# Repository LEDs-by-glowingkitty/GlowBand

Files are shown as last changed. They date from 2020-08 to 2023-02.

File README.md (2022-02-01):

GlowBand is an exciting LED wristband. For dancing at parties and festivals, for long-time exposure photography, and for everyday situations that need some light.

This project started as "The Glowing Arms Project" (check out the "GlowBand v0.1" folder) and after experimenting with making the project smaller and based on existing PCBs ("GlowBand v0.2" folder) I decided to instead make a custom PCB design ("GlowBand v1.0"). The PCB design is still in development, but I plan to finish the design in the coming months. Stay tuned!

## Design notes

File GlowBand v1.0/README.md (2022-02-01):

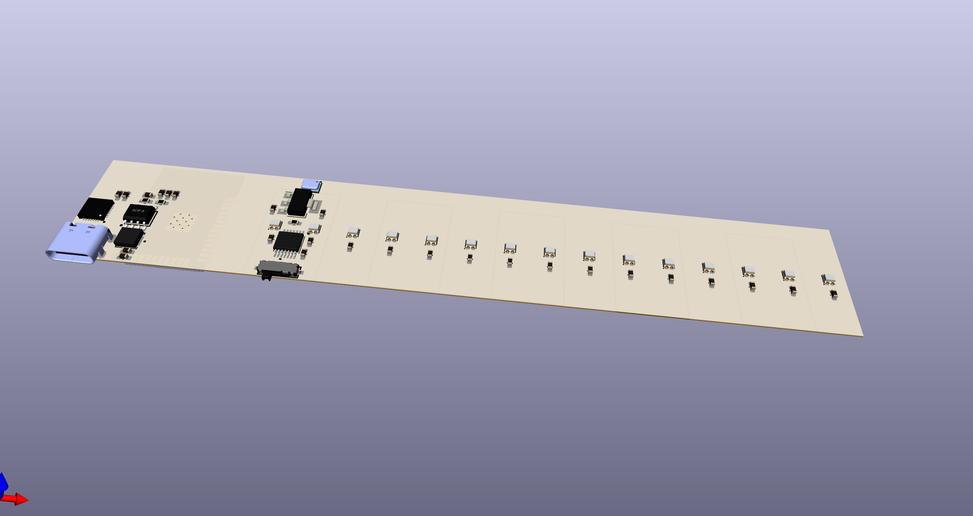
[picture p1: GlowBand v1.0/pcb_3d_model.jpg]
GlowBand


The first version of GlowBand based on a custom PCB design. In development.

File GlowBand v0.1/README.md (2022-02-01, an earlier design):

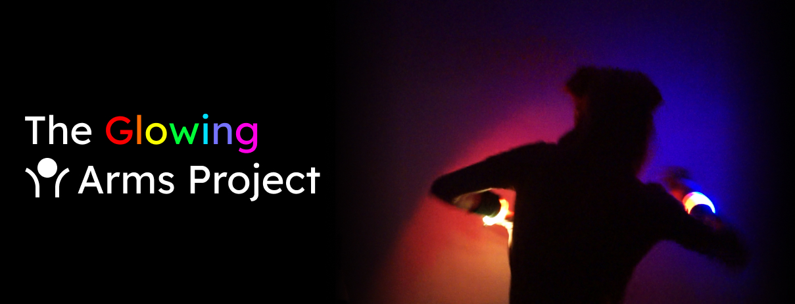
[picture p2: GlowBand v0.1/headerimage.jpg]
The Glowing Arms Project


Build your own LED wristbands for dancing. Controllable via iOS &amp; Android apps. No coding is required.

Want to support the development and stay updated?

<a href="https://www.patreon.com/bePatron?u=24983231">Become a Patreon</a> <a href="https://liberapay.com/glowingkitty/donate">Donate using Liberapay</a>

## Features

- controllable via Bluetooth using the Govee Home [iOS](https://apps.apple.com/us/app/govee-home/id1395696823) and [Android](https://play.google.com/store/apps/details?id=com.govee.home&hl=en) apps
- "Music Mode", reacting to music using the integrated microphone
- "Custom Color Mode", let the LEDs glow in whatever color you like
- and more modes, using the app

## How to build it
Watch this video to learn how you can build the LED wristbands yourself:

[How to build LED wristbands for dancing - no coding required!](https://www.youtube.com/watch?v=rtVQ7AlgY54)
IMAGE ALT TEXT HERE (https://www.youtube.com/watch?v=rtVQ7AlgY54)

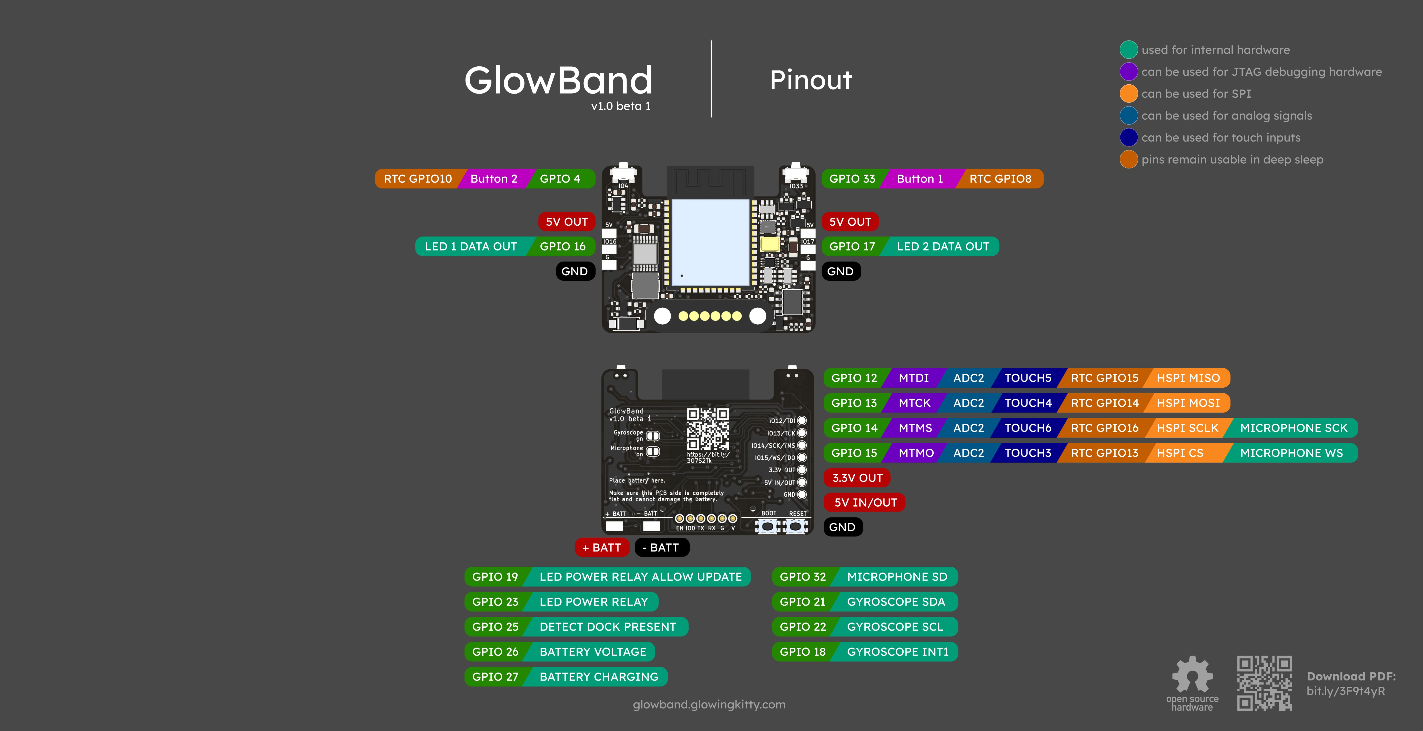
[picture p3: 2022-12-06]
documents/pinout GlowBand v1.0 beta 1.jpg

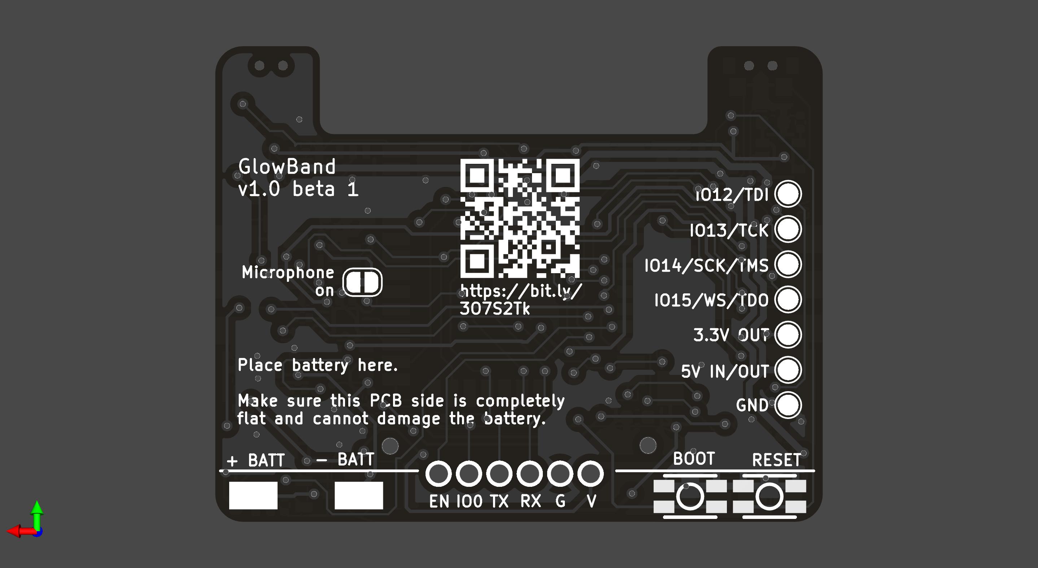
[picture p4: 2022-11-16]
GlowBand PCB/pcb_back.jpg

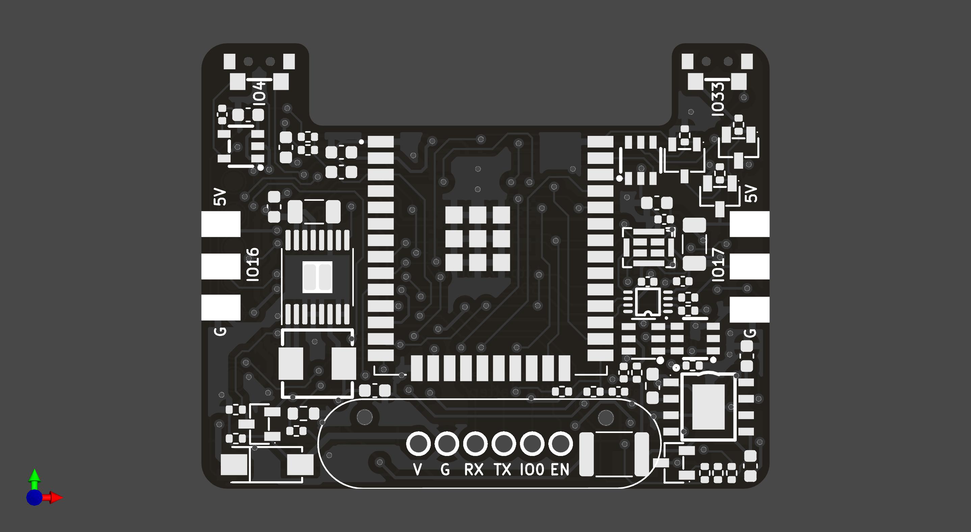
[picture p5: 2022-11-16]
GlowBand PCB/pcb_front.jpg

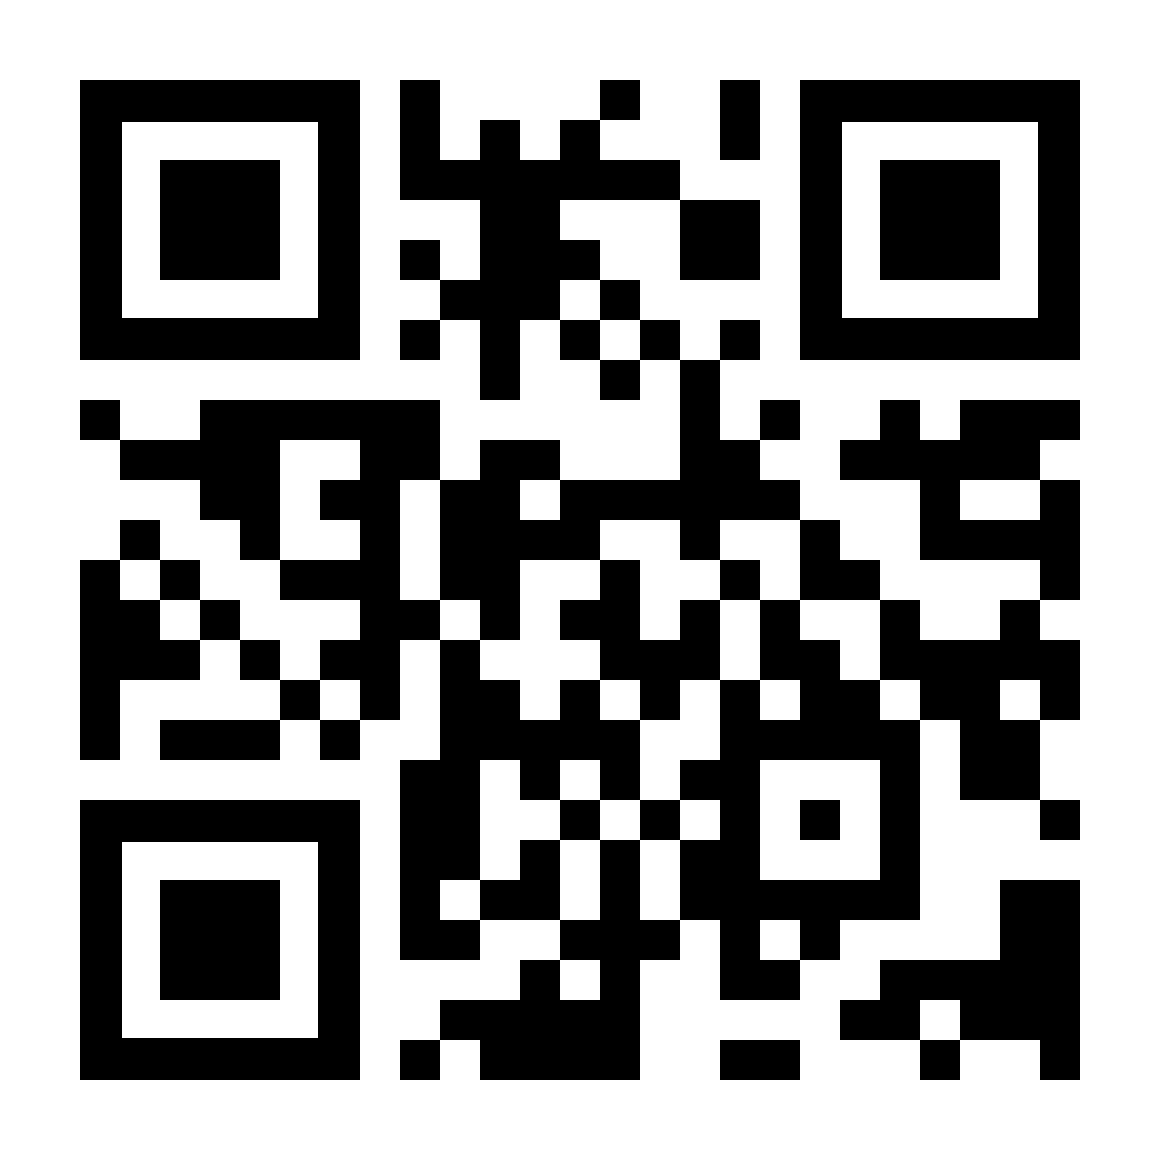
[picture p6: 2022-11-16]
GlowBand PCB/pcb_files.png

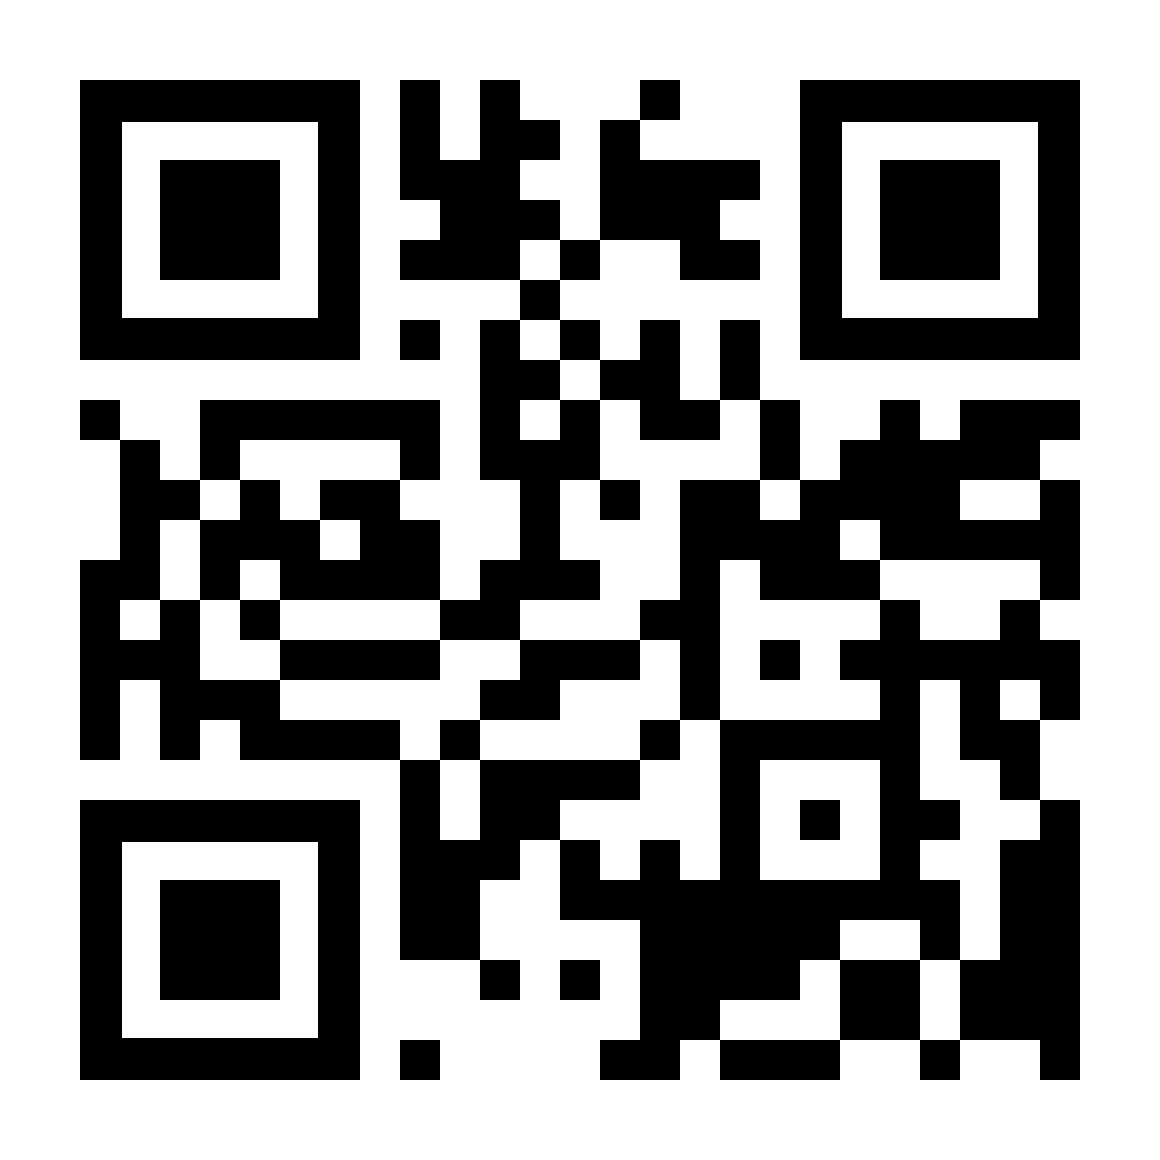
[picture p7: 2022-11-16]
GlowBand Dock PCB/pcb_files.png

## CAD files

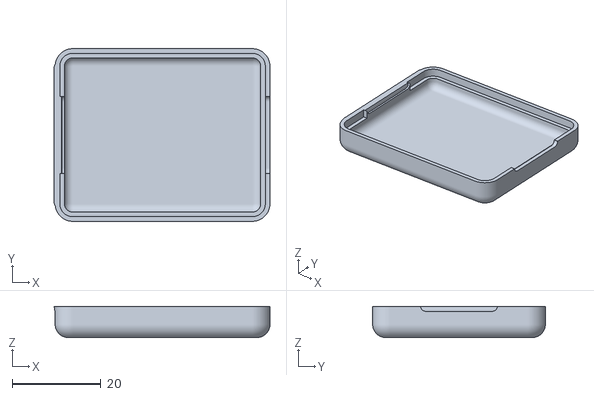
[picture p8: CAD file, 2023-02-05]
3D files/case top.obj
48.8 x 39.0 x 7.05

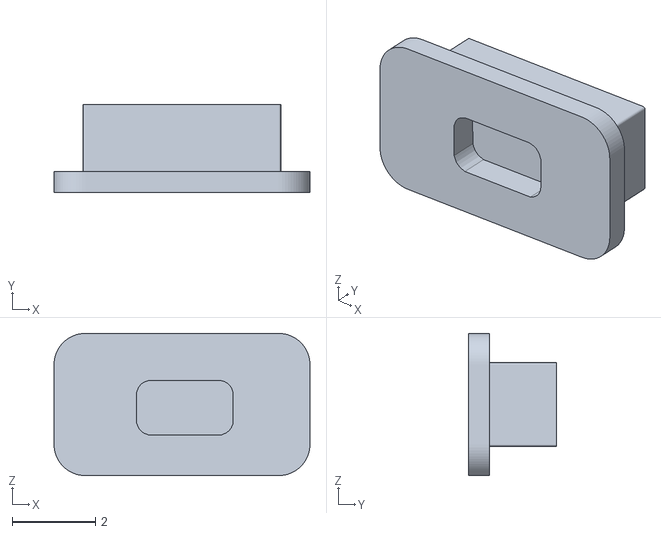
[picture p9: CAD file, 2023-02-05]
3D files/button.obj
6.14 x 2.10 x 3.41

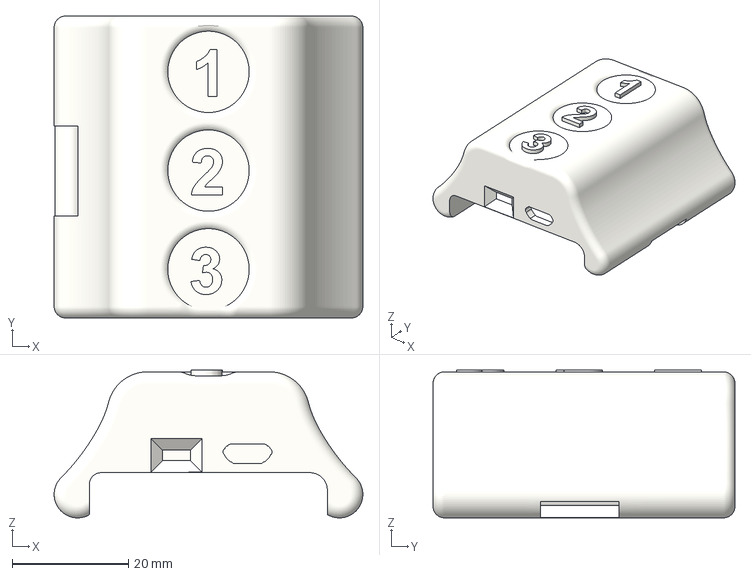
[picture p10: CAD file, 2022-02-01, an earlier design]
archive/GlowBand v0.2/3d printed parts/main case.3mf
53.2 x 52.0 x 25.5 mm

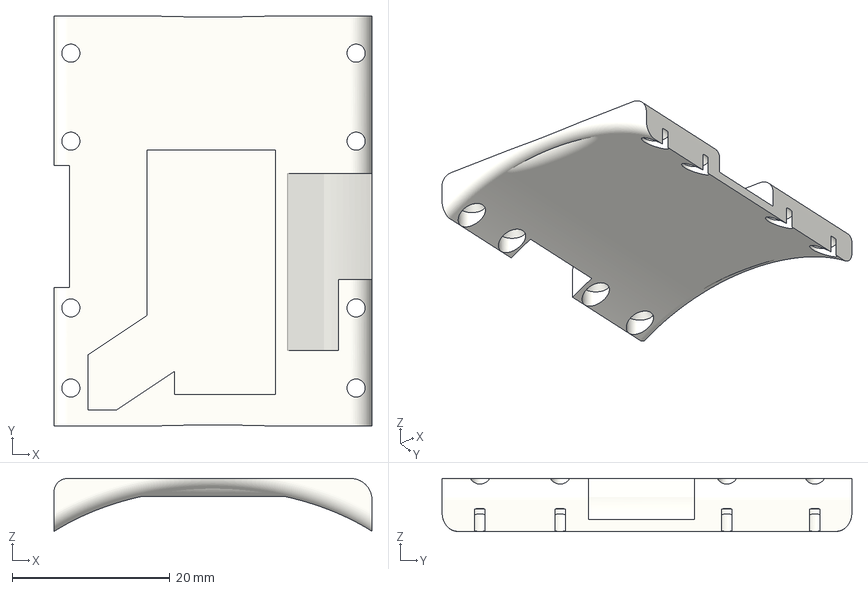
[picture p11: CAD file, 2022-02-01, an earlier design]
archive/GlowBand v0.2/3d printed parts/case cover.3mf
40.4 x 52.0 x 6.73 mm

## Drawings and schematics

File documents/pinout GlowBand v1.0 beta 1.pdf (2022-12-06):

GlowBand | Pinout

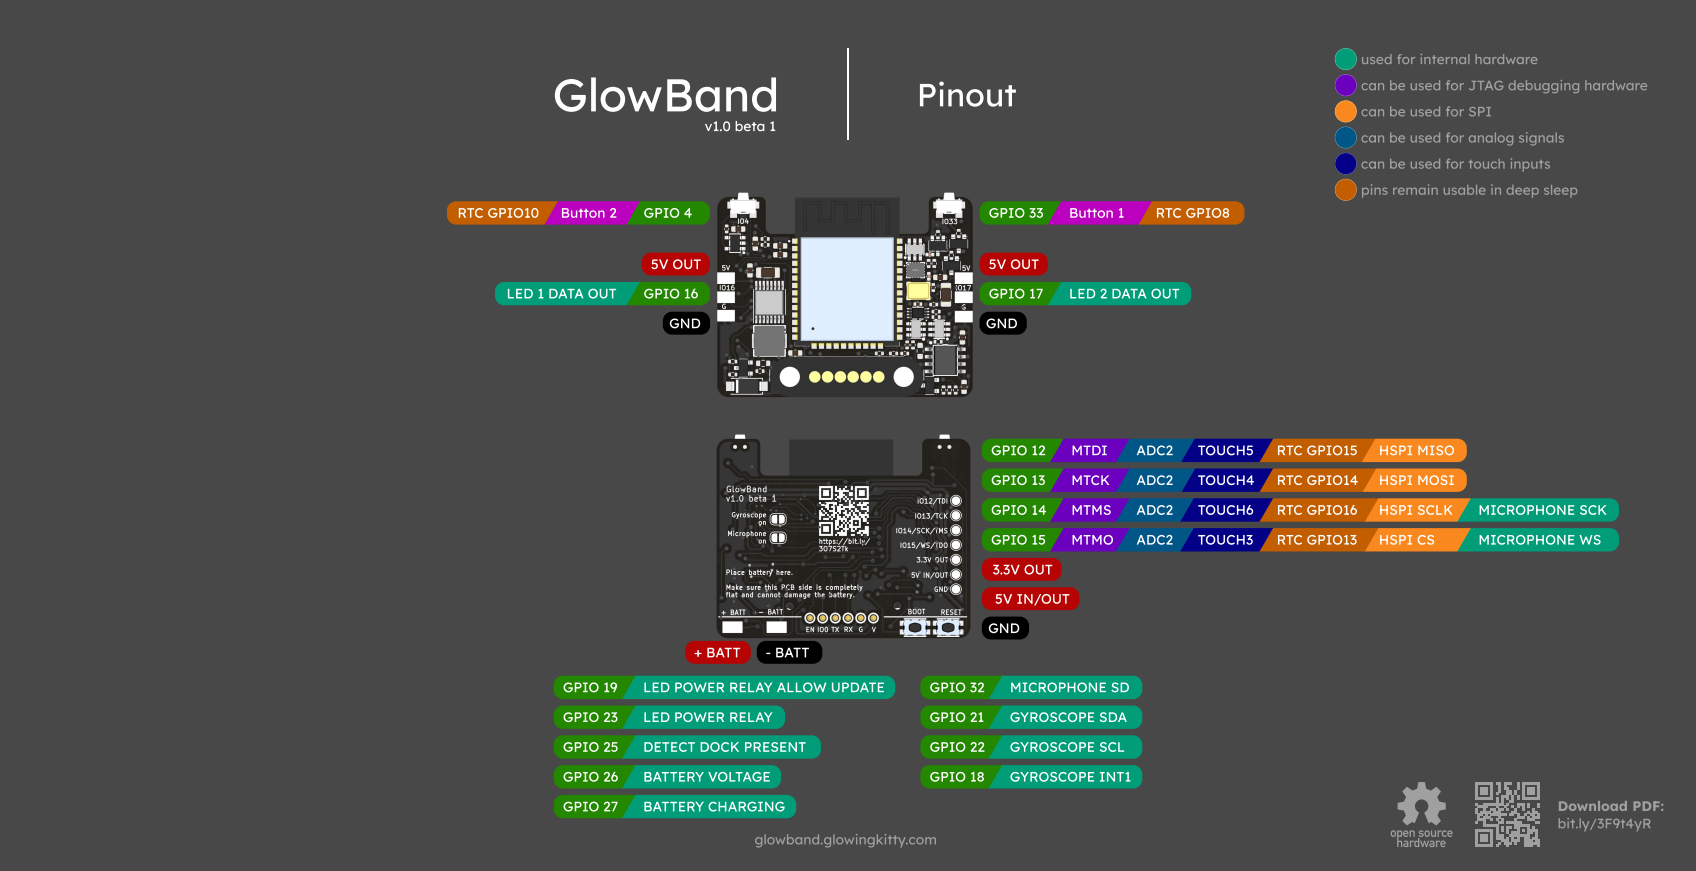
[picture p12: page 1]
GPIO 25; DETECT DOCK PRESENT; GPIO 26; BATTERY VOLTAGE; GPIO 27; BATTERY CHARGING; GPIO 21; GYROSCOPE SDA; GPIO 22; GYROSCOPE SCL; GPIO 18; GYROSCOPE INT1; GPIO 19; LED POWER RELAY ALLOW UPDATE; GPIO 32; MICROPHONE SD; GPIO 23; LED POWER RELAY; v1.0 beta 1; GPIO 33; Button 1; RTC GPIO8; 3.3V OUT; + BATT; 5V IN/OUT; GND; - BATT; GPIO 17; LED 2 DATA OUT; 5V OUT; RTC GPIO10; Button 2; GPIO 4; GPIO 15; MTMO; ADC2; TOUCH3; RTC GPIO13; HSPI CS; MICROPHONE WS; GPIO 14; MTMS; TOUCH6; RTC GPIO16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

used for internal hardware

can be used for JTAG debugging hardware

can be used for SPI

can be used for analog signals

can be used for touch inputs

pins remain usable in deep sleep

5V OUT

LED 1 DATA OUT

GPIO 16

glowband.glowingkitty.com

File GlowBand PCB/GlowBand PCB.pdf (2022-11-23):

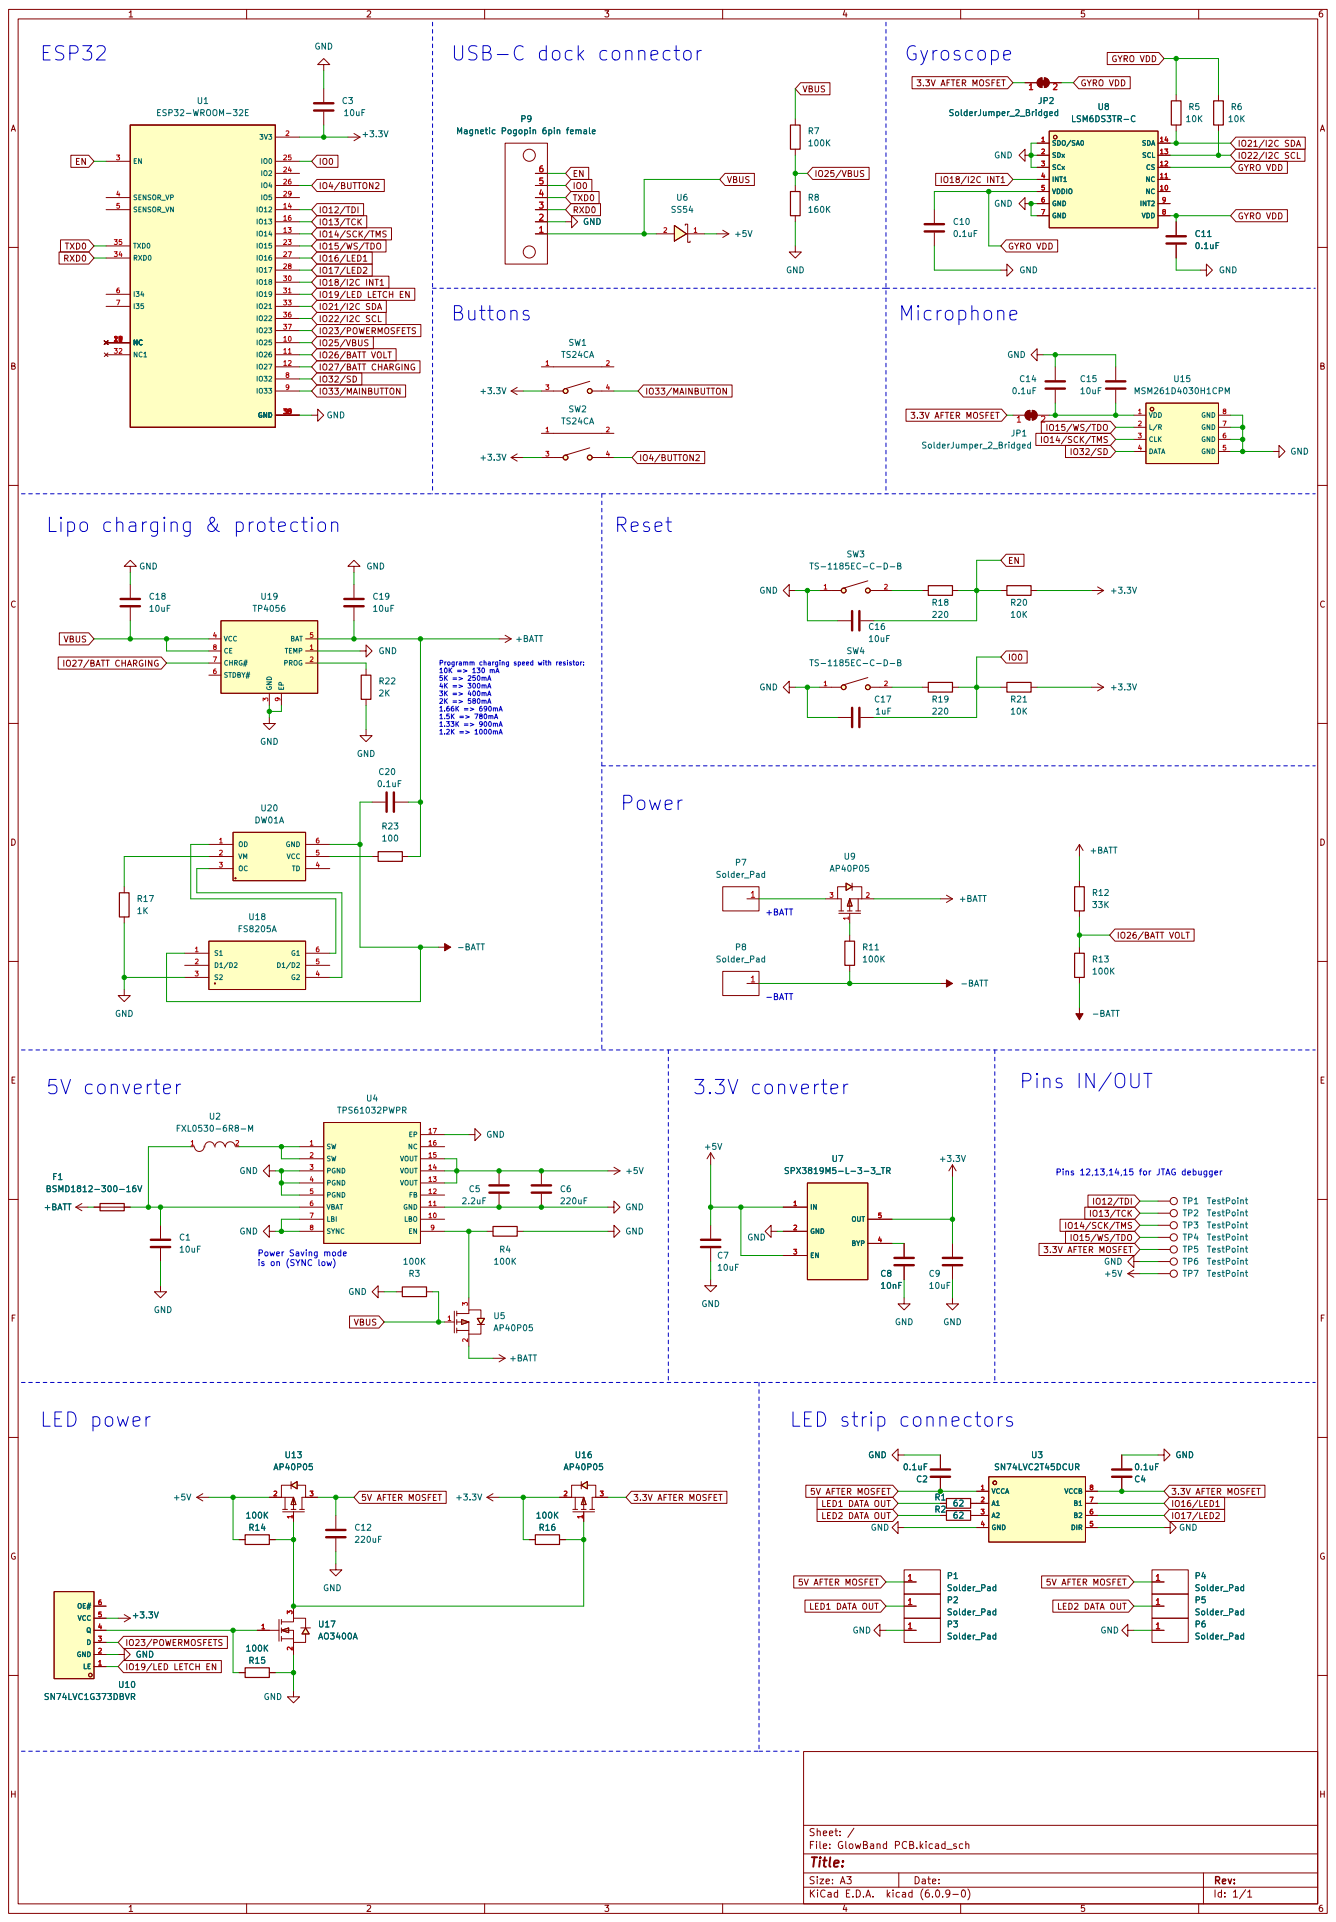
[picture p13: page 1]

3 VCC 4 BAT 5 STDBY# 6 CHRG# 7 CE 8 EP

Programm charging speed with resistor: 10K => 130 mA 5K => 250mA

Pins 12,13,14,15 for JTAG debugger

TP7 TestPoint TP3 TestPoint TP1 TestPoint TP2 TestPoint

Power Saving mode
is on (SYNC low)

File: GlowBand PCB.kicad_sch Sheet: /

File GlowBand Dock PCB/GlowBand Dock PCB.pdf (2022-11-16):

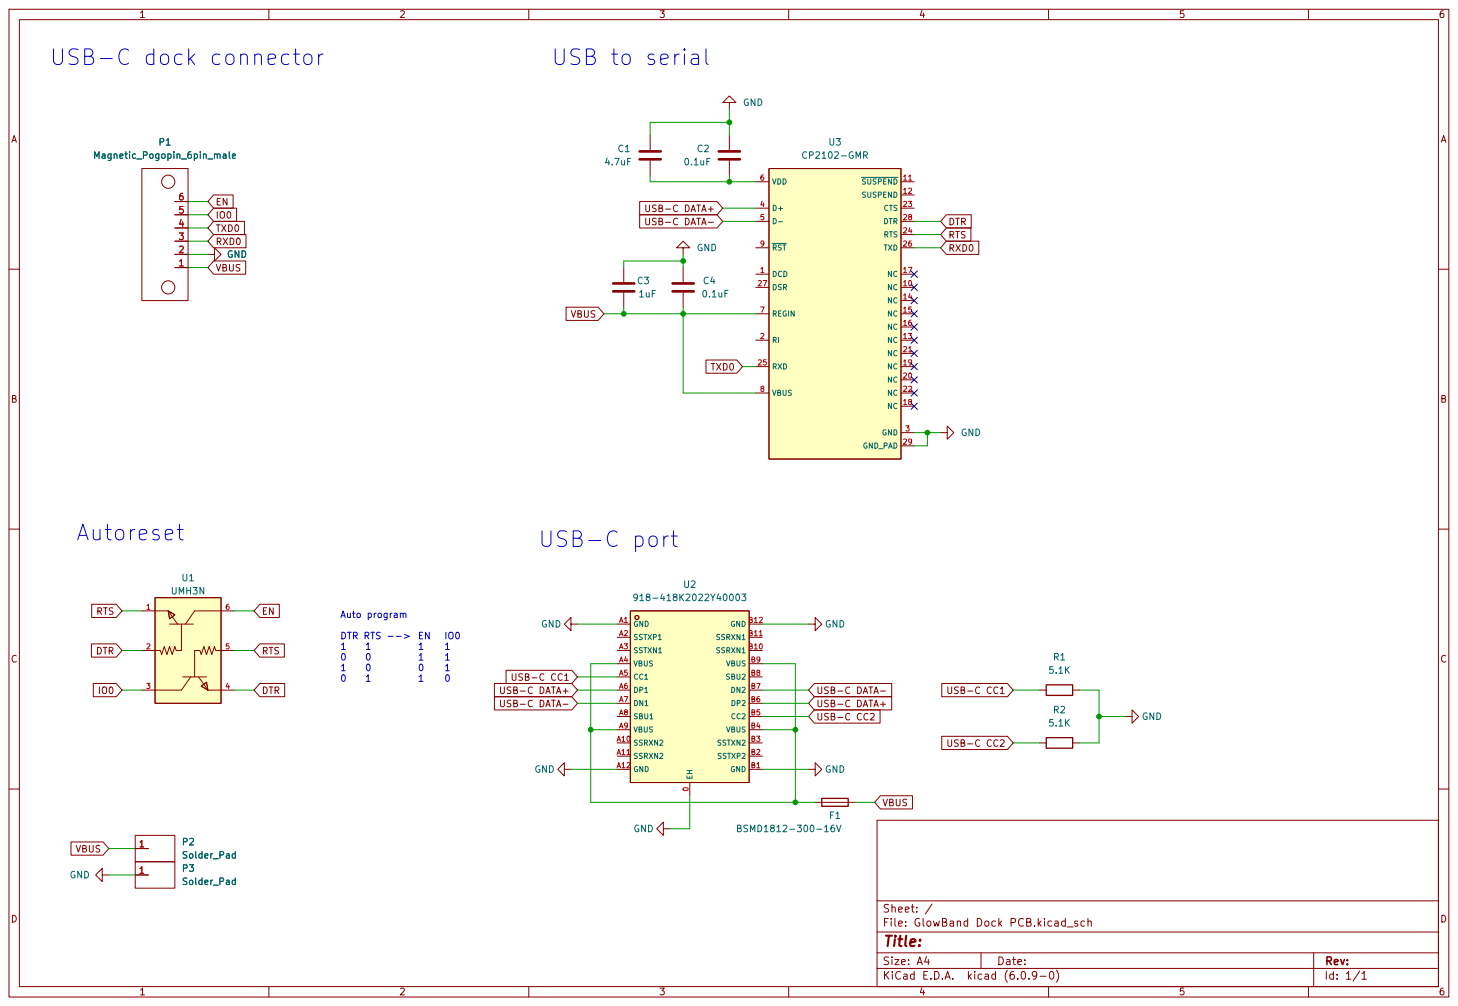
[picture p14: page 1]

0 GND A1 SSRXN2 A10 SSRXN2 A11 GND A12 SSTXP1 A2 SSTXN1 A3 VBUS A4 CC1 A5 DP1 A6 DN1 A7 SBU1 A8 VBUS A9 GND B1 SSRXN1 B10 SSRXN1 B11 GND B12 SSTXP2 B2 SSTXN2 B3 VBUS B4 CC2 B5 DP2 B6 DN2 B7 SBU2 B8 VBUS B9 U2
918-418K2022Y40003 GND

File: GlowBand Dock PCB.kicad_sch Sheet: /
Id: 1/1 Title:

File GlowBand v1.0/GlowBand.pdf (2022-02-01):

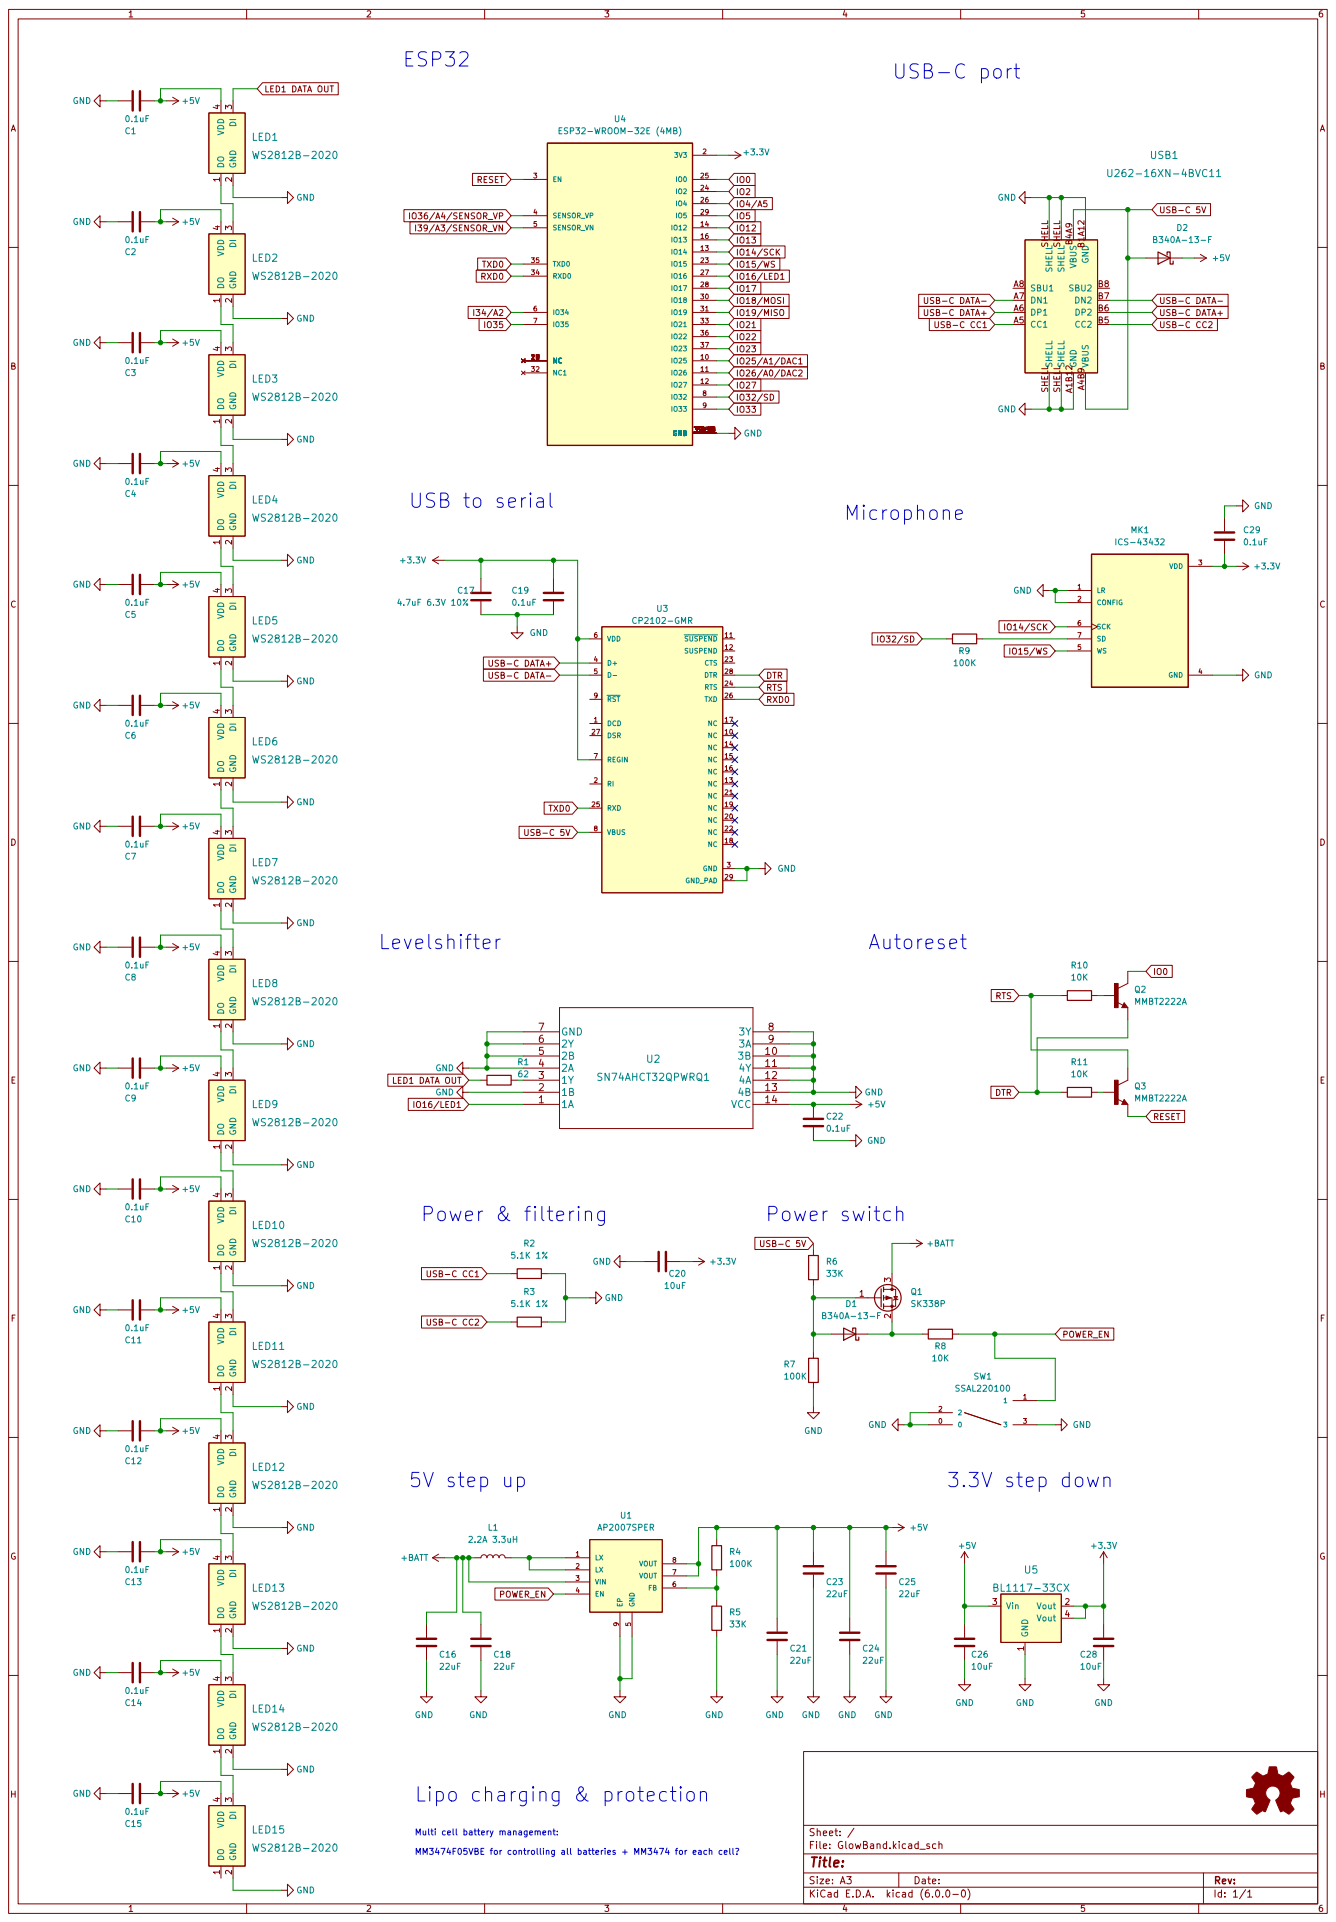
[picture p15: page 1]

Microphone USB to serial

RTS USB-C 5V Power switch

5 FB 6 VOUT 7 VOUT 8 EP

Multi cell battery management:

MM3474F05VBE for controlling all batteries + MM3474 for each cell?

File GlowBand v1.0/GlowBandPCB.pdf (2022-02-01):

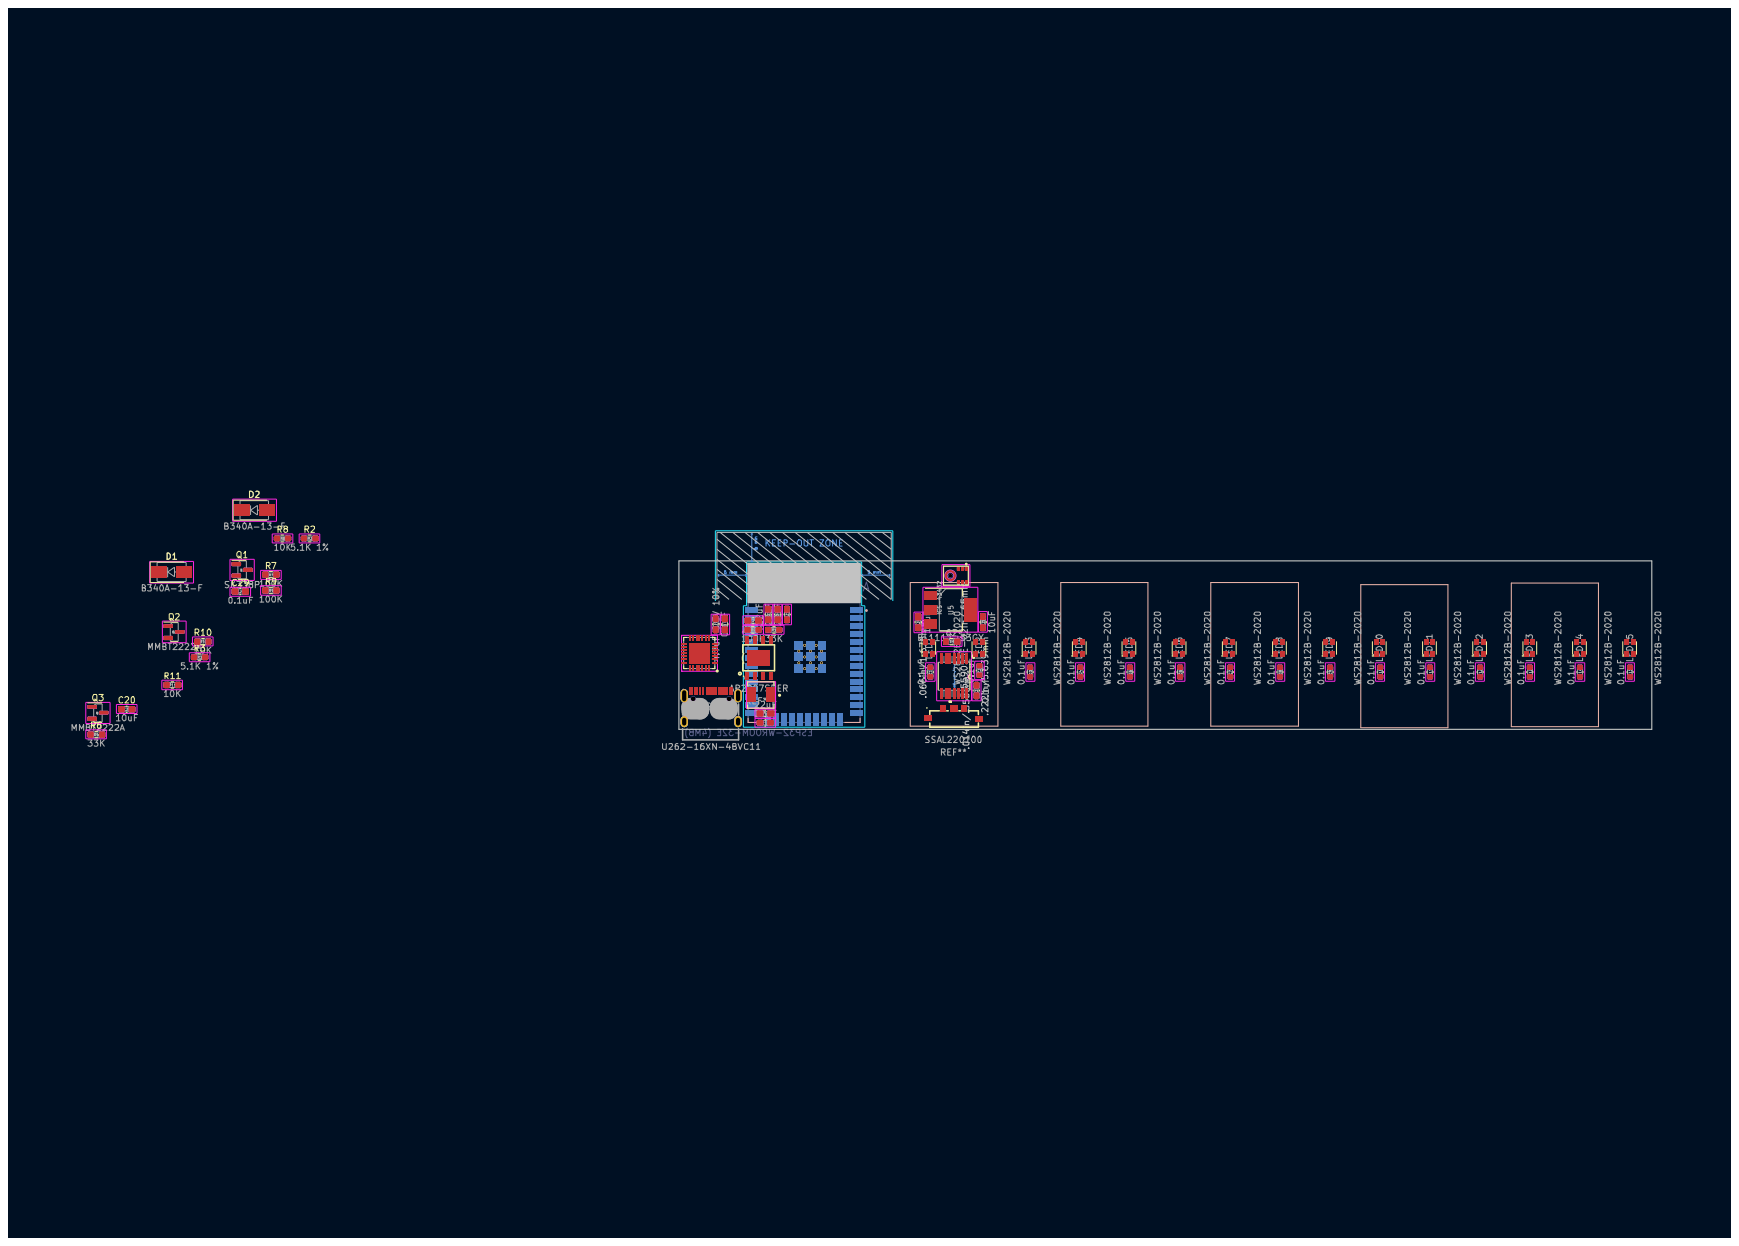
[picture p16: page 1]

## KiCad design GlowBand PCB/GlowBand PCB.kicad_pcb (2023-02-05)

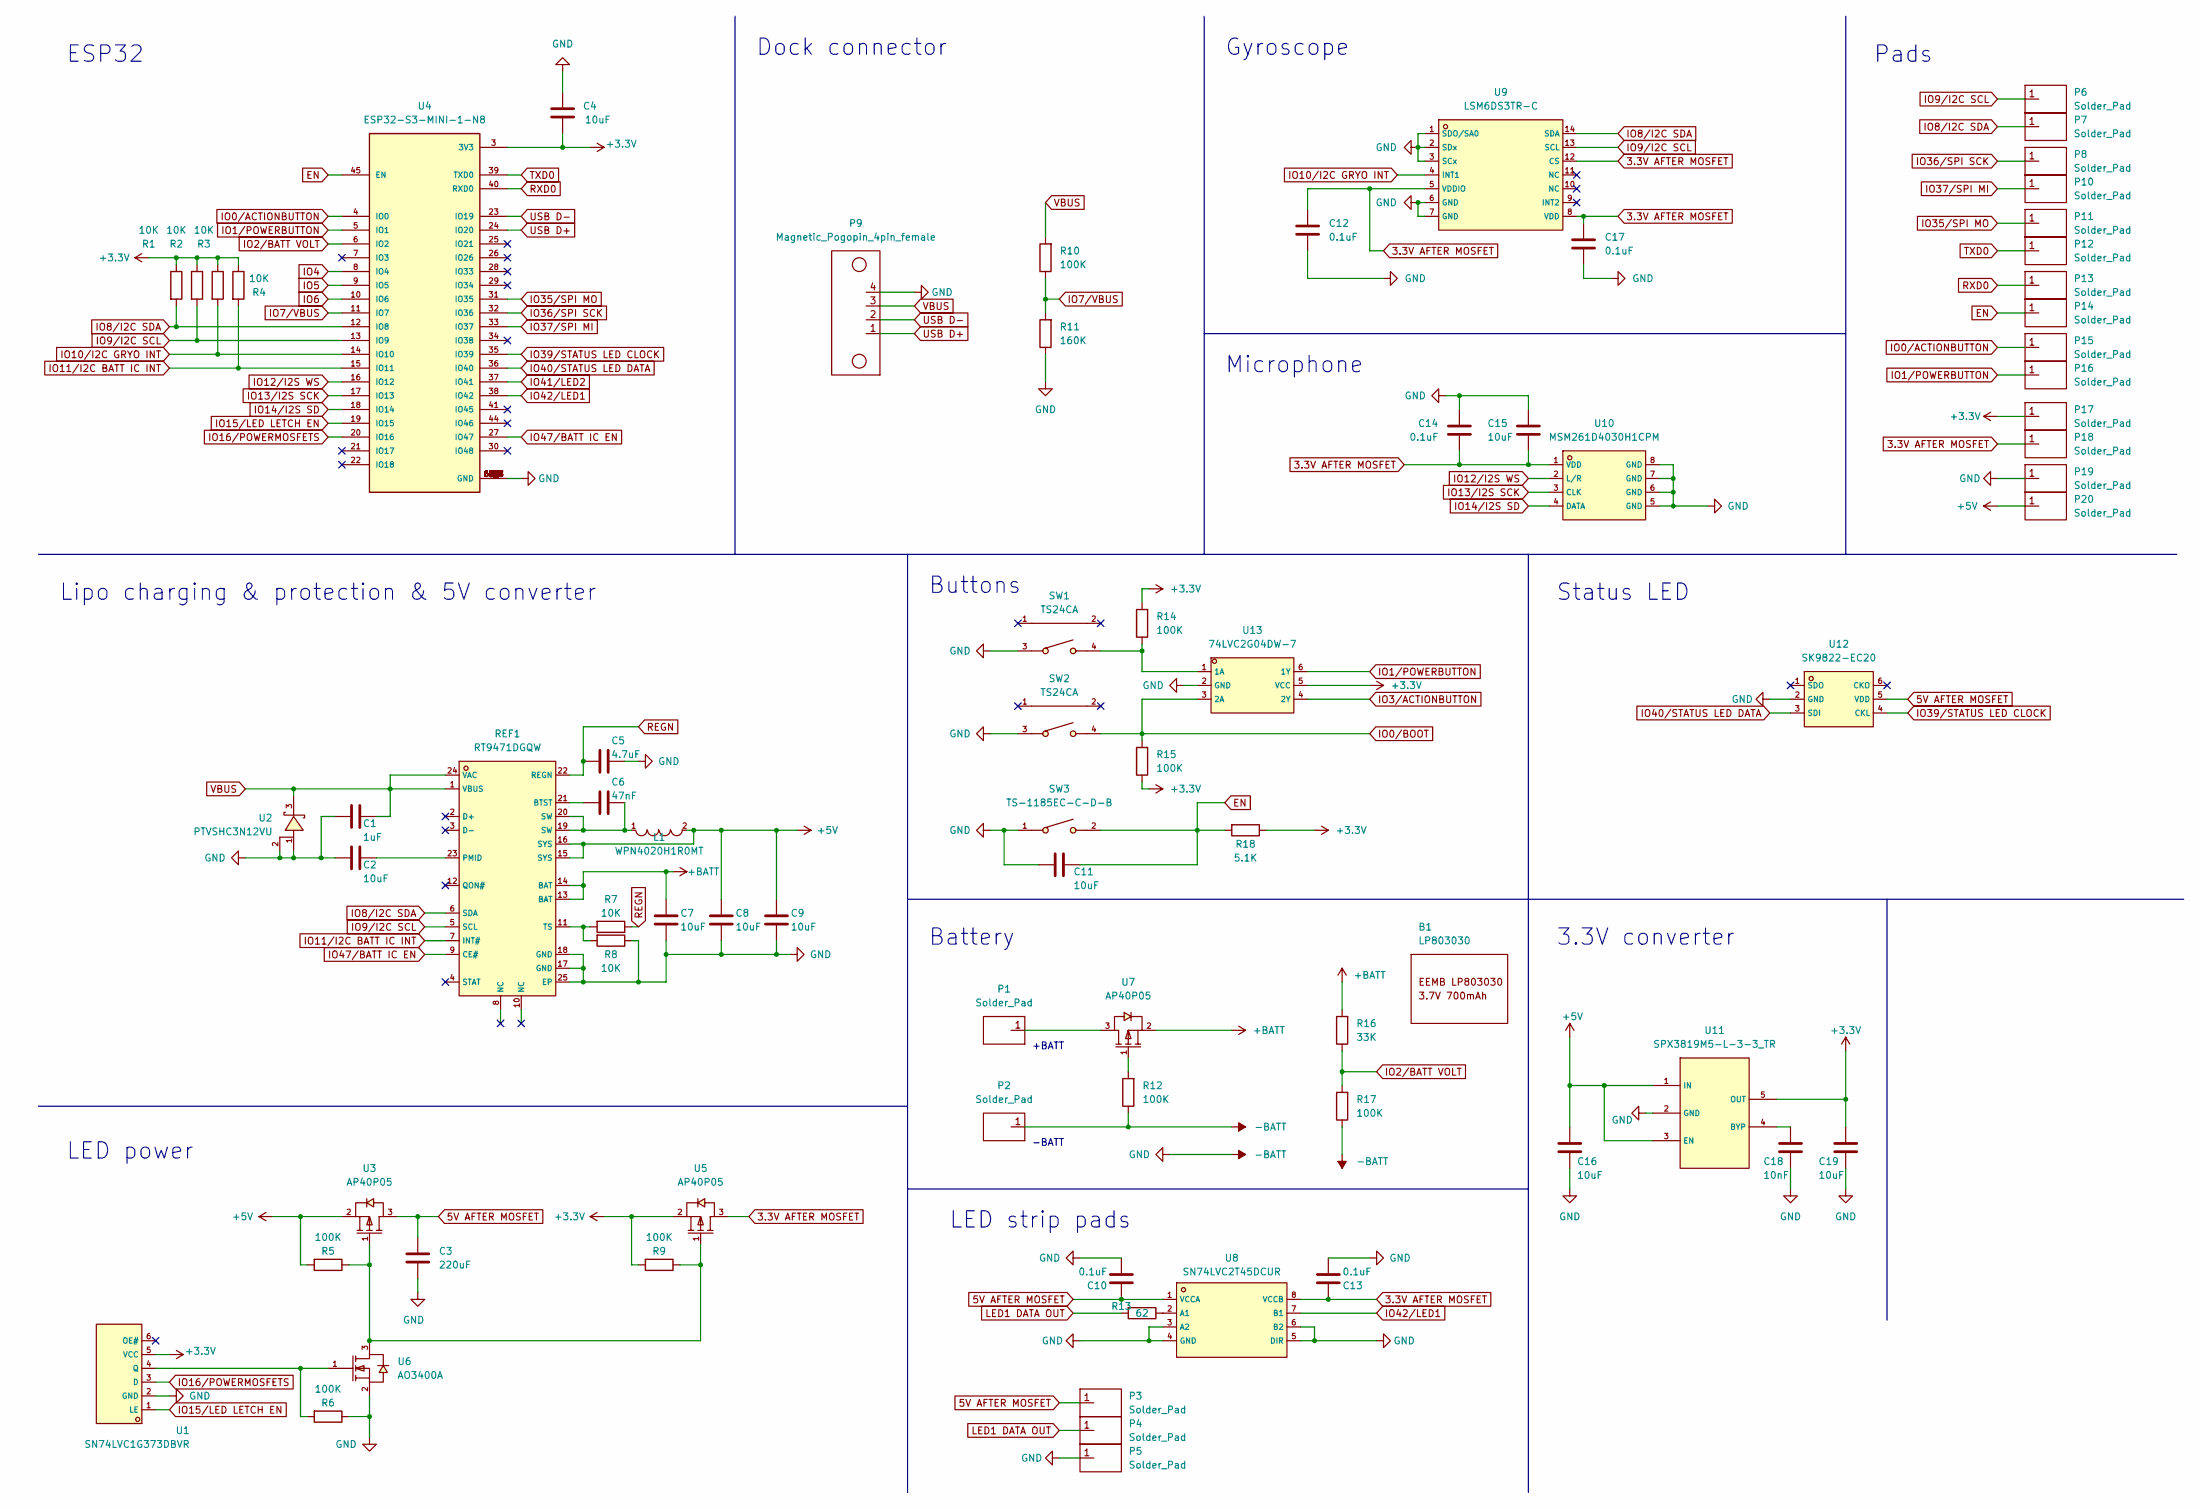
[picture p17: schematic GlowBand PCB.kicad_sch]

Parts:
B1: LP803030
C1: 1uF; C_0402_1005Metric; LCSC # C52923
C2, C4, C7, C8, C9, C15, C16, C19: 10uF; C_0603_1608Metric; LCSC # C96446
C3: 220uF; C_1206_3216Metric; LCSC # C412252
C5: 4.7uF; C_0402_1005Metric; LCSC # C23733
C6: 47nF; C_0402_1005Metric; LCSC # C505502
C10, C12, C13, C14, C17: 0.1uF; C_0402_1005Metric; LCSC # C1525
C11: 10uF; C_0603_1608Metric; LCSC # C19702
C18: 10nF; C_0402_1005Metric; LCSC # C15195
L1: WPN4020H1R0MT; IND-SMD_L4.0-W4.0_SLW40XX; LCSC C98359
P1, P2, P3, P4, P5, P6, P7, P8, P10, P11, P12, P13, P14, P15, P16, P17, P18, P19, P20: Solder_Pad; Solder pad
P9: Magnetic_Pogopin_4pin_female; Magnetic Pogopin 4pin female
R1, R2, R3, R4, R7, R8: 10K; R_0402_1005Metric; LCSC # C25744
R5, R6, R9, R10, R12, R14, R15, R17: 100K; R_0402_1005Metric; LCSC # C25741
R11: 160K; R_0603_1608Metric; LCSC # C22813
R13: 62; R_0402_1005Metric; LCSC # C4962
R16: 33K; R_0402_1005Metric; LCSC # C25779
R18: 5.1K; R_0402_1005Metric; LCSC # C25905
REF1: RT9471DGQW; RT9471_vias_in_pad; LCSC C2839437
SW1, SW2: TS24CA; SW-SMD_TS24CA; LCSC C393942
SW3: TS-1185EC-C-D-B; SW-SMD_4P-L3.7-W3.0-P1.50-LS4.7; LCSC # C318893
U1: SN74LVC1G373DBVR; SOT-23-6_L2.9-W1.6-P0.95-LS2.8-BR; LCSC C128413
U2: PTVSHC3N12VU; DFN-3_L2.0-W2.0-P1.30-BR; LCSC C110755
U3, U5, U7: AP40P05; SOT-23-3_L2.9-W1.3-P1.90-LS2.4-BR; LCSC # C2886385
U4: ESP32-S3-MINI-1-N8; LCSC# C2913206
U6: AO3400A; SOT-23-3_L2.9-W1.6-P1.90-LS2.8-BR; LCSC # C20917
U8: SN74LVC2T45DCUR; VSSOP-8_L2.4-W2.1-P0.50-LS3.2-BR; LCSC # C15741
U9: LSM6DS3TR-C; LGA-14_L3.0-W2.5-P0.50-TL; LCSC C967633
U10: MSM261D4030H1CPM; MIC-SMD_8P-L3.0-W4.0-P0.85-BL; LCSC # C966942
U11: SPX3819M5-L-3-3_TR; SOT-23-5_L3.0-W1.7-P0.95-LS2.8-BR; LCSC # C9055
U12: SK9822-EC20; LED-SMD_6P-L2.0-W2.0-P0.80-TL; LCSC C2909059
U13: 74LVC2G04DW-7; SOT-363_L2.0-W1.3-P0.65-LS2.1-BR; LCSC C69053

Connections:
3.3V AFTER MOSFET: C12.1, C13.1, C14.2, C15.2, C17.1, P18.1, U5.3 (D), U8.8 (VCCB), U9.5 (VDDIO), U9.8 (VDD), U9.12 (CS), U10.1 (VDD)
5V AFTER MOSFET: C3.1, C10.1, P3.1, U3.3 (D), U8.1 (VCCA), U12.5 (VDD)
+3V3: C4.2, C19.2, P17.1, R1.1, R2.1, R3.1, R4.1, R9.2, R14.2, R15.1, R18.1, U1.5 (VCC), U4.3 (3V3), U5.2 (S), U11.5 (OUT), U13.5 (VCC)
+5V: C8.2, C9.2, C16.2, L1.2, P20.1, R5.2, REF1.15 (SYS), REF1.16 (SYS), U3.2 (S), U11.1 (IN), U11.3 (EN)
+BATT: C7.2, R16.2, REF1.13 (BAT), REF1.14 (BAT), U7.2 (S)
-BATT: C1.1, C2.1, C3.2, C4.1, C5.2, C7.1, C8.1, C9.1, C10.2, C11.1, C12.2, C13.2, C14.1, C15.1, C16.1, C17.2, C18.1, C19.1, P2.1, P5.1, P9.4, P19.1, R6.1, R8.1, R11.1, R12.1, R17.1, REF1.17 (GND), REF1.18 (GND), REF1.25 (EP), SW1.3, SW2.3, SW3.1, U1.2 (GND), U2.1 (A), U2.2 (1), U4.1 (GND), U4.2 (GND), U4.42 (GND), U4.43 (GND), U4.46 (GND), U4.47 (GND), U4.48 (GND), U4.49 (GND), U4.50 (GND), U4.51 (GND), U4.52 (GND), U4.53 (GND), U4.54 (GND), U4.55 (GND), U4.56 (GND), U4.57 (GND), U4.58 (GND), U4.59 (GND), U4.60 (GND), U4.61 (GND), U4.61_1 (GND), U4.61_2 (GND), U4.61_3 (GND), U4.61_4 (GND), U4.61_5 (GND), U4.61_6 (GND), U4.61_7 (GND), U4.61_8 (GND), U4.62 (GND), U4.63 (GND), U4.64 (GND), U4.65 (GND), U6.2 (S), U8.3 (A2), U8.4 (GND), U8.5 (DIR), U8.6 (B2), U9.1 (SDO/SA0), U9.2 (SDx), U9.3 (SCx), U9.6 (GND), U9.7 (GND), U10.5 (GND), U10.6 (GND), U10.7 (GND), U10.8 (GND), U11.2 (GND), U12.2 (GND), U13.2 (GND)
EN: C11.2, P14.1, R18.2, SW3.2, U4.45 (EN)
IO0/ACTIONBUTTON: P15.1, U4.4 (IO0)
IO0/BOOT: R15.2, SW2.4, U13.3 (2A)
IO1/POWERBUTTON: P16.1, U4.5 (IO1), U13.6 (1Y)
IO2/BATT VOLT: R16.1, R17.2, U4.6 (IO2)
IO3/ACTIONBUTTON: U13.4 (2Y)
IO4: U4.8 (IO4)
IO5: U4.9 (IO5)
IO6: U4.10 (IO6)
IO7/VBUS: R10.1, R11.2, U4.11 (IO7)
IO8/I2C SDA: P7.1, R1.2, REF1.6 (SDA), U4.12 (IO8), U9.14 (SDA)
IO9/I2C SCL: P6.1, R2.2, REF1.5 (SCL), U4.13 (IO9), U9.13 (SCL)
IO10/I2C GRYO INT: R3.2, U4.14 (IO10), U9.4 (INT1)
IO11/I2C BATT IC INT: R4.2, REF1.7 (INT#), U4.15 (IO11)
IO12/I2S WS: U4.16 (IO12), U10.2 (L/R)
IO13/I2S SCK: U4.17 (IO13), U10.3 (CLK)
IO14/I2S SD: U4.18 (IO14), U10.4 (DATA)
IO15/LED LETCH EN: U1.1 (LE), U4.19 (IO15)
IO16/POWERMOSFETS: U1.3 (D), U4.20 (IO16)
IO35/SPI MO: P11.1, U4.31 (IO35)
IO36/SPI SCK: P8.1, U4.32 (IO36)
IO37/SPI MI: P10.1, U4.33 (IO37)
IO39/STATUS LED CLOCK: U4.35 (IO39), U12.4 (CKL)
IO40/STATUS LED DATA: U4.36 (IO40), U12.3 (SDI)
IO41/LED2: U4.37 (IO41)
IO42/LED1: U4.38 (IO42), U8.7 (B1)
IO47/BATT IC EN: REF1.9 (CE#), U4.27 (IO47)
LED1 DATA OUT: P4.1, R13.2
unnamed: C2.2, REF1.23 (PMID)
unnamed: C6.1, REF1.21 (BTST)
unnamed: C6.2, L1.1, REF1.19 (SW), REF1.20 (SW)
unnamed: C18.2, U11.4 (BYP)
unnamed: P1.1, U7.3 (D)
unnamed: R5.1, R9.1, U3.1 (G), U5.1 (G), U6.3 (D)
unnamed: R6.2, U1.4 (Q), U6.1 (G)
unnamed: R7.2, R8.2, REF1.11 (TS)
unnamed: R12.2, U7.1 (G)
unnamed: R13.1, U8.2 (A1)
unnamed: R14.1, SW1.4, U13.1 (1A)
REGN: C5.1, R7.1, REF1.22 (REGN)
RXD0: P13.1, U4.40 (RXD0)
TXD0: P12.1, U4.39 (TXD0)
USB D+: P9.1, U4.24 (IO20)
USB D-: P9.2, U4.23 (IO19)
VBUS: C1.2, P9.3, R10.2, REF1.1 (VBUS), REF1.24 (VAC), U2.3 (K)

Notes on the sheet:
+BATT
Dock connector
ESP32
LED strip pads
Buttons
LED power
3.3V converter
Status LED
Gyroscope
Microphone
-BATT
Lipo charging & protection & 5V converter
Pads
Battery

Board: 2 copper layers, 76 parts (18 on the bottom side), 46 nets, no tracks yet.

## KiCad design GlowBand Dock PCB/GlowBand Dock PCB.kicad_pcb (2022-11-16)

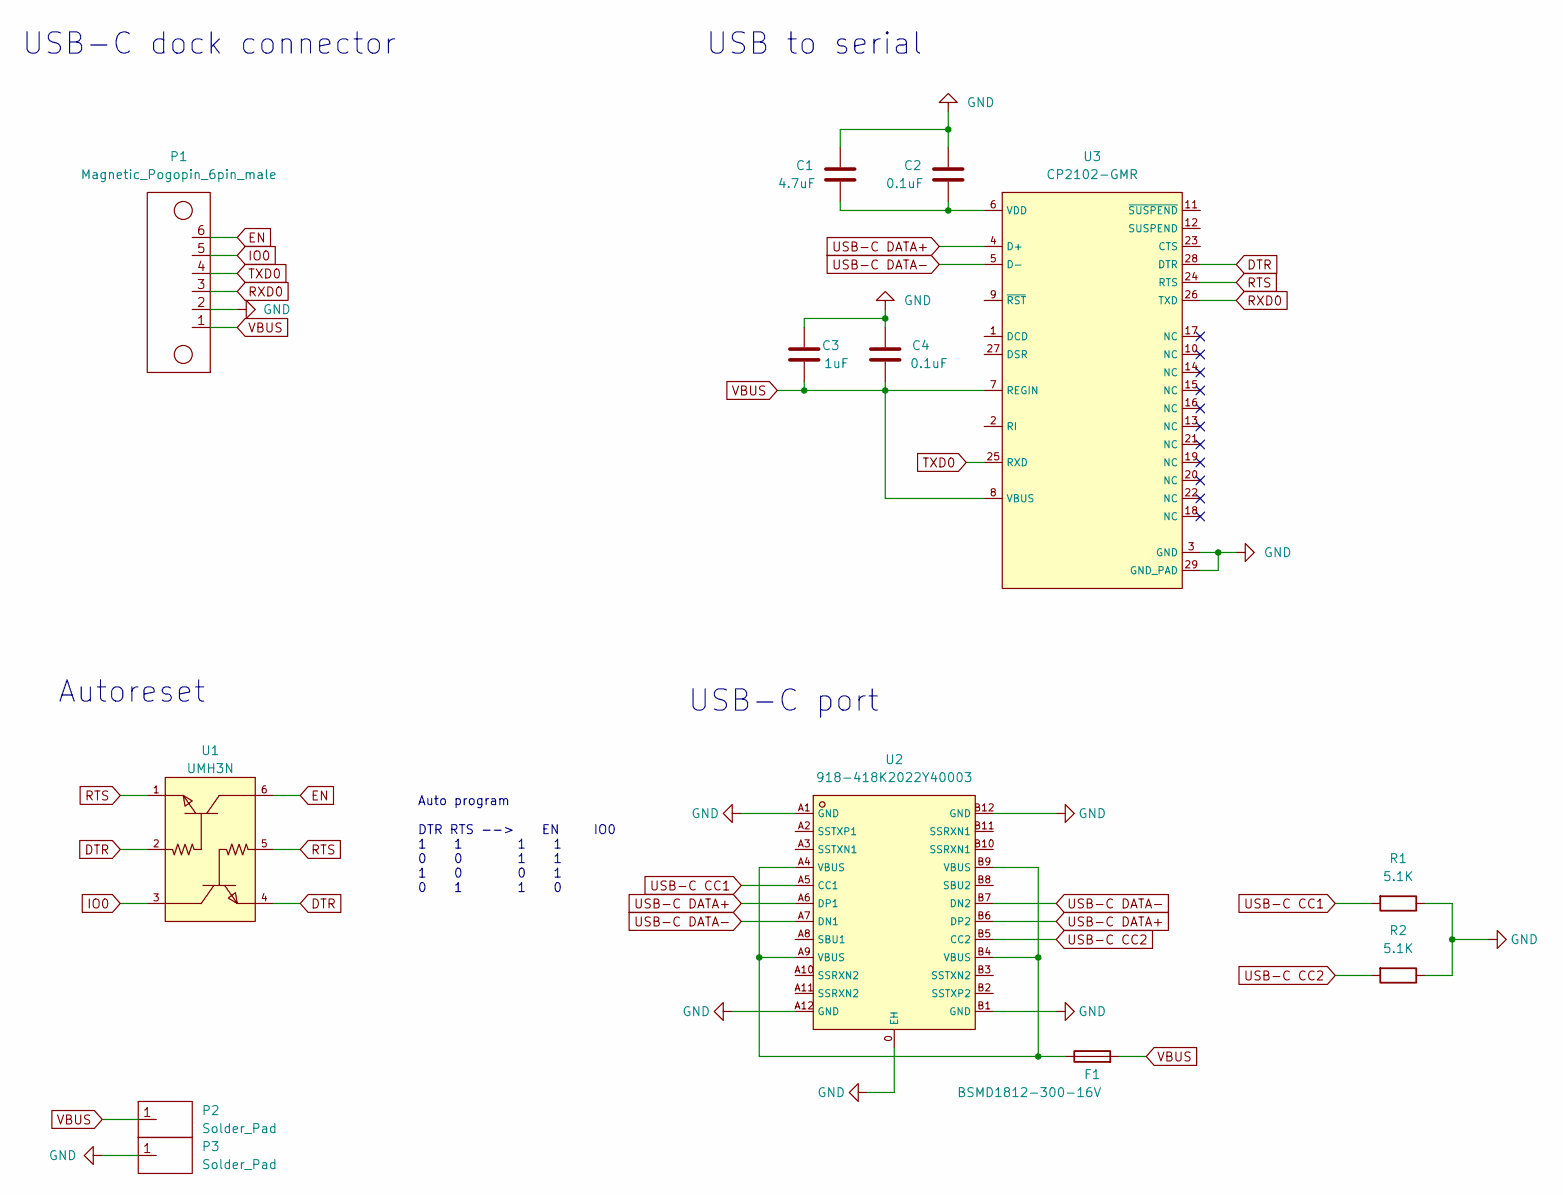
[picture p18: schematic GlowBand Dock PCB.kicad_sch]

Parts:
C1: 4.7uF; C_0603_1608Metric; LCSC # C19666
C2, C4: 0.1uF; C_0402_1005Metric; LCSC # C1525
C3: 1uF; C_0402_1005Metric; LCSC # C52923
F1: BSMD1812-300-16V; Fuse_1812_4532Metric; LCSC # C883162
P1: Magnetic_Pogopin_6pin_male; Magnetic Pogopin 6pin male
P2, P3: Solder_Pad; Solder pad
R1, R2: 5.1K; R_0402_1005Metric; LCSC # C25905
U1: UMH3N; SC-70-6_L2.2-W1.3-P0.65-LS2.1-BR; LCSC # C62892
U2: 918-418K2022Y40003; TYPE-C-SMD_918-418K2022Y40003; LCSC C67382
U3: CP2102-GMR; QFN-28_L5.0-W5.0-P0.50-BL-EP; LCSC # C6568

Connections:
DTR: U1.2 (B), U1.4 (E), U3.28 (DTR)
EN: P1.6, U1.6 (C)
GND: C1.2, C2.1, C3.2, C4.2, P1.2, P3.1, R1.1, R2.1, U2.0 (EH), U2.A1 (GND), U2.A12 (GND), U2.B1 (GND), U2.B12 (GND), U3.3 (GND), U3.29 (GND_PAD)
IO0: P1.5, U1.3 (C)
unnamed: C1.1, C2.2, U3.6 (VDD)
unnamed: F1.1, U2.A4 (VBUS), U2.A9 (VBUS), U2.B4 (VBUS), U2.B9 (VBUS)
RTS: U1.1 (E), U1.5 (B), U3.24 (RTS)
RXD0: P1.3, U3.26 (TXD)
TXD0: P1.4, U3.25 (RXD)
USB-C CC1: R1.2, U2.A5 (CC1)
USB-C CC2: R2.2, U2.B5 (CC2)
USB-C DATA+: U2.A6 (DP1), U2.B6 (DP2), U3.4 (D+)
USB-C DATA-: U2.A7 (DN1), U2.B7 (DN2), U3.5 (D-)
VBUS: C3.1, C4.1, F1.2, P1.1, P2.1, U3.7 (REGIN), U3.8 (VBUS)

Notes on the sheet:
Autoreset
USB-C port
USB-C dock connector
USB to serial
Auto program DTR RTS --> EN IO0 1 1 1 1 0 0 1 1 1 0 0 1 0 1 1 0

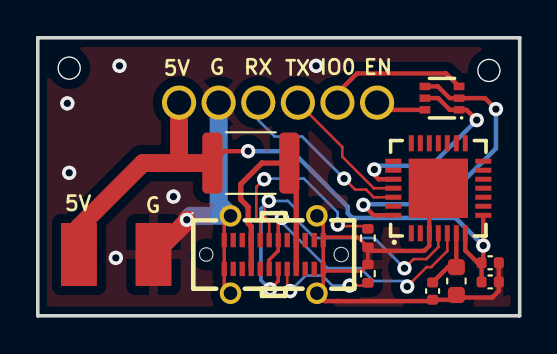
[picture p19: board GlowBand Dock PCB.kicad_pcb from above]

Board: 2 copper layers, 26.8 x 15.4 mm, 13 parts (1 on the bottom side), 14 nets.

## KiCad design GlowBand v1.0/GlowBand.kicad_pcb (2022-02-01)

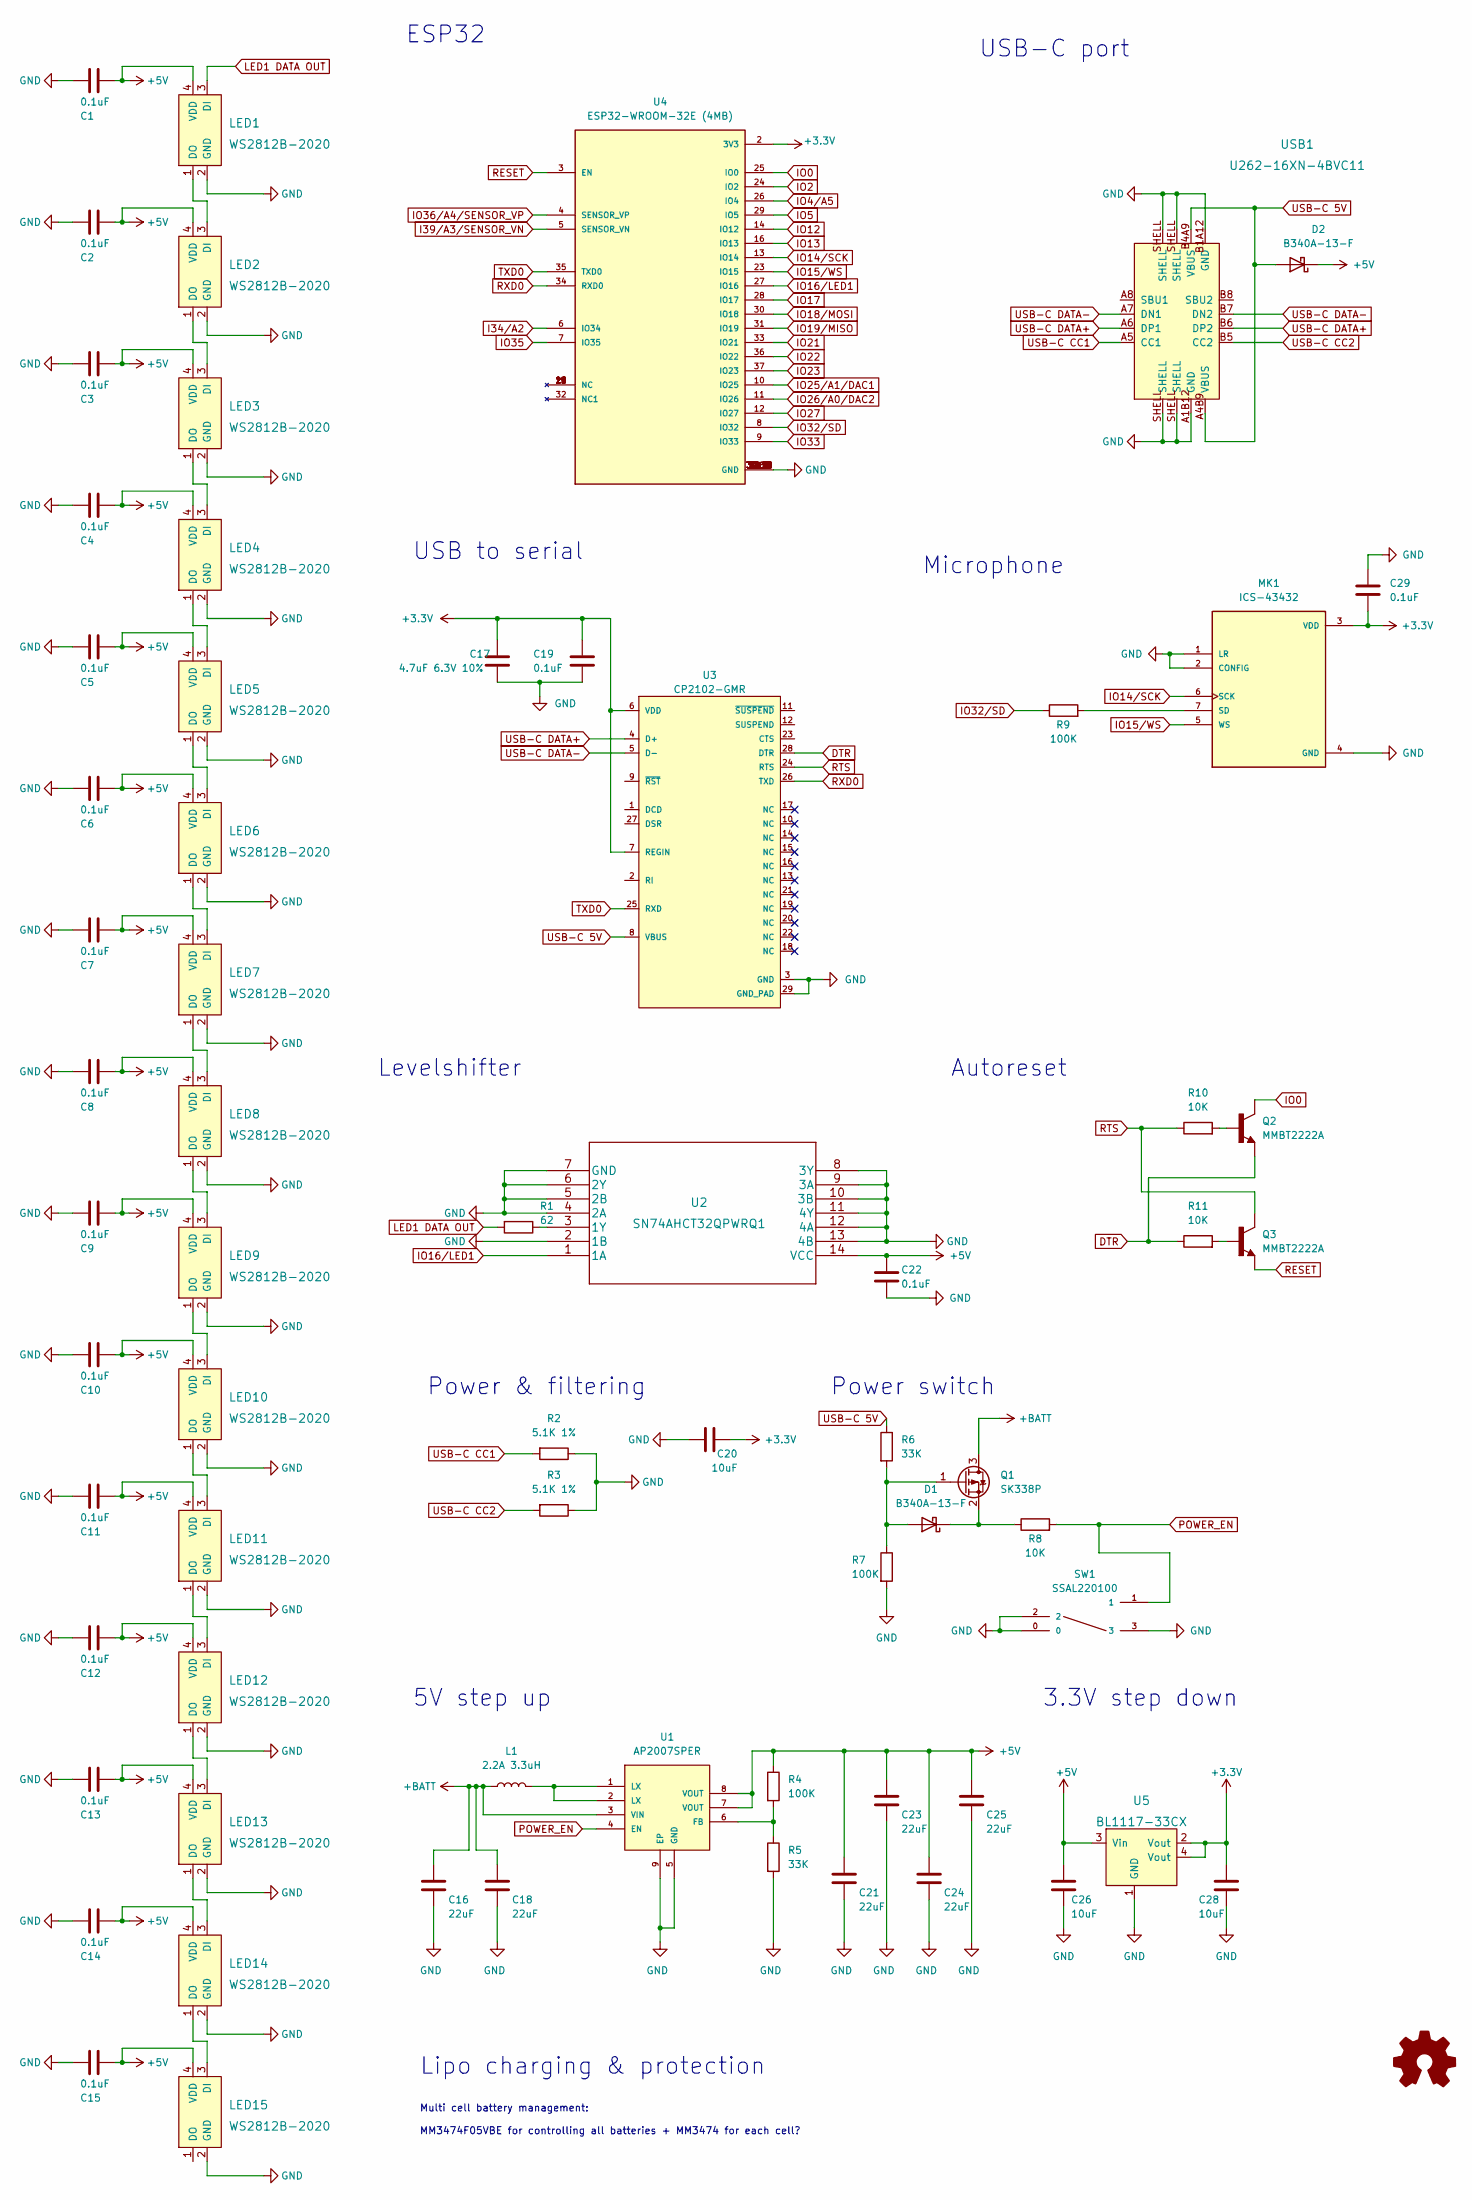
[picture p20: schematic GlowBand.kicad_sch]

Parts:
C1, C2, C3, C4, C5, C6, C7, C8, C9, C10, C11, C12, C13, C14, C15: 0.1uF; C_0603_1608Metric; Mfr. Part # 06035C104K4Z2A; LCSC Part # C597194
C16, C18, C21, C23, C24, C25: 22uF; C_0603_1608Metric_Pad1.08x0.95mm_HandSolder
C17: 4.7uF 6.3V 10%; C_0603_1608Metric_Pad1.08x0.95mm_HandSolder
C19, C29: 0.1uF; C_0603_1608Metric_Pad1.08x0.95mm_HandSolder; Mfr. Part # 06035C104K4Z2A; LCSC Part # C597194
C20, C26, C28: 10uF; C_0603_1608Metric_Pad1.08x0.95mm_HandSolder; Mfr. Part # C0603X5R106K250NT; LCSC Part # C729457
C22: 0.1uF; C_0603_1608Metric_Pad1.08x0.95mm_HandSolder
D1, D2: B340A-13-F; D_SMA; Mfr. Part # B340A-13-F; LCSC Part # C85098
L1: 2.2A 3.3uH; FDSD0412
LED1, LED2, LED3, LED4, LED5, LED6, LED7, LED8, LED9, LED10, LED11, LED12, LED13, LED14, LED15: WS2812B-2020; Mfr. Part # WS2812B-2020; LCSC Part # C965555
MK1: ICS-43432; MIC_ICS-43432; Mfr. Part # ICS-43432; LCSC Part # C574021
Q1: SK338P; SOT-23; Mfr. Part # SK338P; LCSC Part # C475695
Q2, Q3: MMBT2222A; SOT-23; Mfr. Part # MMBT2222A; LCSC Part # C545537
R1: 62; R_0603_1608Metric_Pad0.98x0.95mm_HandSolder
R2, R3: 5.1K 1%; R_0603_1608Metric_Pad0.98x0.95mm_HandSolder; Mfr. Part # HPCR0603F5K10K9; LCSC Part # C365193
R4, R7, R9: 100K; R_0603_1608Metric_Pad0.98x0.95mm_HandSolder; Mfr. Part # 0603WAF1003T5E; LCSC Part # C25803
R5, R6: 33K; R_0603_1608Metric_Pad0.98x0.95mm_HandSolder
R8: 10K; R_0603_1608Metric_Pad0.98x0.95mm_HandSolder
R10, R11: 10K; R_0603_1608Metric_Pad0.98x0.95mm_HandSolder; Mfr. Part # RC0603FR-0710KL; LCSC Part # C98220
SW1: SSAL220100
U1: AP2007SPER; Mfr. Part # AP2007SPER; LCSC Part # C130338
U2: SN74AHCT32QPWRQ1; Mfr. Part # SN74AHCT32QPWRQ1; LCSC Part # C507218
U3: CP2102-GMR; mouser part number 634-CP2102-GMR; digikey description USB Bridge, USB to UART USB 2.0 UART In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
U4: ESP32-WROOM-32E (4MB); MODULE_ESP32-WROOM-32E_(16MB); Mfr. Part # ESP32-WROOM-32E(4MB); LCSC Part # C701341
U5: BL1117-33CX; SOT-223; Mfr. Part # BL1117-33CX; LCSC Part # C5400
USB1: U262-16XN-4BVC11; USB-3.1-SMD_U262-161N-4BVC11; Mfr. Part # U262-161N-4BVC11; LCSC Part # C319148

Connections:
+3V3: C17.2, C19.1, C20.1, C28.2, C29.2, MK1.3 (VDD), U3.6 (VDD), U3.7 (REGIN), U4.2 (3V3), U5.2 (Vout), U5.4 (Vout)
+5V: C1.1, C2.1, C3.1, C4.1, C5.1, C6.1, C7.1, C8.1, C9.1, C10.1, C11.1, C12.1, C13.1, C14.1, C15.1, C21.1, C22.1, C23.1, C24.1, C25.1, C26.2, D2.1 (K), LED1.4 (VDD), LED2.4 (VDD), LED3.4 (VDD), LED4.4 (VDD), LED5.4 (VDD), LED6.4 (VDD), LED7.4 (VDD), LED8.4 (VDD), LED9.4 (VDD), LED10.4 (VDD), LED11.4 (VDD), LED12.4 (VDD), LED13.4 (VDD), LED14.4 (VDD), LED15.4 (VDD), R4.1, U1.7 (VOUT), U1.8 (VOUT), U2.14 (VCC), U5.3 (Vin)
+BATT: C16.1, C18.1, L1.1, Q1.3 (D), U1.3 (VIN)
DTR: Q2.2, R11.1, U3.28 (DTR)
GND: C1.2, C2.2, C3.2, C4.2, C5.2, C6.2, C7.2, C8.2, C9.2, C10.2, C11.2, C12.2, C13.2, C14.2, C15.2, C16.2, C17.1, C18.2, C19.2, C20.2, C21.2, C22.2, C23.2, C24.2, C25.2, C26.1, C28.1, C29.1, LED1.2 (GND), LED2.2 (GND), LED3.2 (GND), LED4.2 (GND), LED5.2 (GND), LED6.2 (GND), LED7.2 (GND), LED8.2 (GND), LED9.2 (GND), LED10.2 (GND), LED11.2 (GND), LED12.2 (GND), LED13.2 (GND), LED14.2 (GND), LED15.2 (GND), MK1.1 (LR), MK1.2 (CONFIG), MK1.4 (GND), R2.1, R3.1, R5.2, R7.2, SW1.0, SW1.2, SW1.3, U1.5 (GND), U1.9 (EP), U2.2 (1B), U2.4 (2A), U2.5 (2B), U2.6 (2Y), U2.7 (GND), U2.8 (3Y), U2.9 (3A), U2.10 (3B), U2.11 (4Y), U2.12 (4A), U2.13 (4B), U3.3 (GND), U3.29 (GND_PAD), U4.1 (GND), U4.15 (GND), U4.38 (GND), U4.39_1 (GND), U4.39_2 (GND), U4.39_3 (GND), U4.39_4 (GND), U4.39_5 (GND), U4.39_6 (GND), U4.39_7 (GND), U4.39_8 (GND), U4.39_9 (GND), U4.39_10 (GND), U4.39_11 (GND), U4.39_12 (GND), U4.39_13 (GND), U4.39_14 (GND), U4.39_15 (GND), U4.39_16 (GND), U4.39_17 (GND), U4.39_18 (GND), U4.39_19 (GND), U4.39_20 (GND), U4.39_21 (GND), U5.1 (GND), USB1.A1B12 (GND), USB1.B1A12 (GND), USB1.SHELL
I34/A2: U4.6 (IO34)
I39/A3/SENSOR_VN: U4.5 (SENSOR_VN)
IO0: Q2.3, U4.25 (IO0)
IO2: U4.24 (IO2)
IO4/A5: U4.26 (IO4)
IO5: U4.29 (IO5)
IO12: U4.14 (IO12)
IO13: U4.16 (IO13)
IO14/SCK: MK1.6 (SCK), U4.13 (IO14)
IO15/WS: MK1.5 (WS), U4.23 (IO15)
IO16/LED1: U2.1 (1A), U4.27 (IO16)
IO17: U4.28 (IO17)
IO18/MOSI: U4.30 (IO18)
IO19/MISO: U4.31 (IO19)
IO21: U4.33 (IO21)
IO22: U4.36 (IO22)
IO23: U4.37 (IO23)
IO25/A1/DAC1: U4.10 (IO25)
IO26/A0/DAC2: U4.11 (IO26)
IO27: U4.12 (IO27)
IO32/SD: R9.1, U4.8 (IO32)
IO33: U4.9 (IO33)
IO35: U4.7 (IO35)
IO36/A4/SENSOR_VP: U4.4 (SENSOR_VP)
LED1 DATA OUT: LED1.3 (DI), R1.2
unnamed: D1.1 (K), Q1.2 (S), R8.1
unnamed: D1.2 (A), Q1.1 (G), R6.2, R7.1
unnamed: L1.2, U1.1 (LX), U1.2 (LX)
unnamed: LED1.1 (DO), LED2.3 (DI)
unnamed: LED2.1 (DO), LED3.3 (DI)
unnamed: LED4.1 (DO), LED5.3 (DI)
unnamed: LED3.1 (DO), LED4.3 (DI)
unnamed: LED6.1 (DO), LED7.3 (DI)
unnamed: LED5.1 (DO), LED6.3 (DI)
unnamed: LED7.1 (DO), LED8.3 (DI)
unnamed: LED8.1 (DO), LED9.3 (DI)
unnamed: LED10.1 (DO), LED11.3 (DI)
unnamed: LED9.1 (DO), LED10.3 (DI)
unnamed: LED11.1 (DO), LED12.3 (DI)
unnamed: LED13.1 (DO), LED14.3 (DI)
unnamed: LED12.1 (DO), LED13.3 (DI)
unnamed: LED14.1 (DO), LED15.3 (DI)
unnamed: MK1.7 (SD), R9.2
unnamed: Q2.1, R10.2
unnamed: Q3.1, R11.2
unnamed: R1.1, U2.3 (1Y)
unnamed: R4.2, R5.1, U1.6 (FB)
POWER_EN: R8.2, SW1.1, U1.4 (EN)
RESET: Q3.2, U4.3 (EN)
RTS: Q3.3, R10.1, U3.24 (RTS)
RXD0: U3.26 (TXD), U4.34 (RXD0)
TXD0: U3.25 (RXD), U4.35 (TXD0)
USB-C 5V: D2.2 (A), R6.1, U3.8 (VBUS), USB1.A4B9 (VBUS), USB1.B4A9 (VBUS)
USB-C CC1: R2.2, USB1.A5 (CC1)
USB-C CC2: R3.2, USB1.B5 (CC2)
USB-C DATA+: U3.4 (D+), USB1.A6 (DP1), USB1.B6 (DP2)
USB-C DATA-: U3.5 (D-), USB1.A7 (DN1), USB1.B7 (DN2)

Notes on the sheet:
ESP32
3.3V step down
USB to serial
Power switch
USB-C port
5V step up
Lipo charging & protection
Microphone
Power & filtering
Multi cell battery management: MM3474F05VBE for controlling all batteries + MM3474 for each cell?
Autoreset
Levelshifter

Board: 2 copper layers, 68 parts (1 on the bottom side), 43 nets, no tracks yet.

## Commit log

2020-05-25 update donate button
2022-02-01 added pcb design for new v1.0 (in dev)
    [GlowBand-CuBottom.gbr, GlowBand-CuTop.gbr, GlowBand-EdgeCuts.gbr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]
2022-08-24 started new design
    [GlowBand.kicad_sch]
2022-11-11 start creating new pcbs
    [GlowBand Dock PCB.kicad_pcb, GlowBand Dock PCB.kicad_sch, GlowBand PCB.kicad_pcb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]
2022-11-16 updated pcbs
    [GlowBand Dock PCB-CuBottom.gbr, GlowBand Dock PCB-CuTop.gbr, GlowBand Dock PCB-EdgeCuts.gbr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]
2022-11-23 added gyroscope to GlowBand
    [GlowBand PCB-CuBottom.gbr, GlowBand PCB-CuTop.gbr, GlowBand PCB-EdgeCuts.gbr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]
2022-12-05 updated pinout
    [GlowBand PCB.kicad_pcb]
2023-02-05 updated pcb design and case prototype
    [GlowBand PCB.kicad_pcb, GlowBand PCB.kicad_sch, button.obj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]

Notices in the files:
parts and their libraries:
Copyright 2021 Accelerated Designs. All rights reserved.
